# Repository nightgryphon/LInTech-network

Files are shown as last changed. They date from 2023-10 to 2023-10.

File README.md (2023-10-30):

# Сеть LInTech
Проект посвящен сбору информации, реконструкции и исследованию учебного сетевого комплекса LInTech для компьютерных классов СССР.

## История
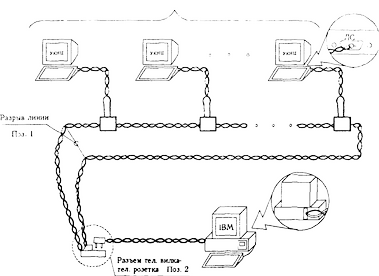
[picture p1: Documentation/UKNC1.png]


Комплекс был [разработан](https://dic.academic.ru/dic.nsf/ruwiki/46187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) в 1990-х гг. ООО «ЛИнТех» («Лаборатория информационных технологий») совместно с ООО «Алтер-Вест»
для модернизации существующих учебных классов на базе ПЭВМ Корвет, УКНЦ и БК0010 для изучения современного на тот момент ПО для IBM PC.

Обеспечивалась работа мест учеников в режимах локальной сети и в терминальном режиме.

Наиболее интересным и необычным для того времени является **терминальный режим**, в котором существующие места учеников становятся сетевыми терминалами для головной машины на базе IBM PC. 
Поддерживаются как режимы текстового терминала для изучения MS DOS, так и графического для изучения MS Windows 3.11. 

В режиме локальной сети ученикам предоставляется доступ к дискам головной машины, причем скорость работы заметно выше штатной учебной сети. 

Комплекс упоминается в [журналах](http://school136.perm.ru/sunduk/samos/info.htm) и документах 
министерства образования и был [рекомендован](http://web.archive.org/web/20070927175919/http://www.informika.ru/text/goscom/normdoc/d_96/PRIK~5/l155.html) к применению в школах.
Однако классы на базе ПЭВМ СССР на тот момент уже активно замещались западными PC, в том числе при активной поддержке западных производителей, 
в результате комплекс LInTech не успел получить широкого распространения и был практически утрачен.

В настоящее время ученические платы изредка встречаются в ПЭВМ, списаных из школ. Чаще всего это ПЭВМ Корвет, реже УКНЦ, также известно несколько экземпляров плат для БК. 
Долгое время не удавалось разыскать сетевую плату и ПО головной машины, без которых невозможна работа ни одной из этих сетей. 
На данный момент доподлинно известно о двух сохранившихся экземплярах головной платы и, возможно, еще одном.

Первый и пока единственный публично упомянутый запуск-реконструкция сети LInTech / NET-Rt11 осуществлены [Arseny](http://uknc.narod.ru/) для ПЭВМ УКНЦ (МС 0511). 
На его сайте представлены [качественные фото плат](http://uknc.narod.ru/Img/index.htm) и [комплект учительского ПО для УКНЦ](http://uknc.narod.ru/Net-RT11/index.htm).
Однако задача реконструкции комплекса на данном этапе была существенно затруднена отсутствием копии защищенной от чтения прошивки микроконтроллера головной платы.

Второй экземпляр головной платы и бумажную документацию удалось разыскать [Serebriakov](https://github.com/paulargent). 
Благодаря его усилиям были налажены контакты с разработчиками из ЛИнТех, получено оставшееся в архивах ПО и прошивки контроллера головной платы.
Это решило принципиальный вопрос с прошивками и сделало возможной дальнейшую реконструкцию системы. Также есть надежда, что со временем появится и электронная версия найденной документации.

Мне удалось разыскать и восстановить клиентские платы БК0010 и УКНЦ, найти около десятка контроллеров от платы головной машины (увы, без самих плат). 

Все это позволяет попробовать реконструировать и запустить сеть ЛИнТех.

## Реконструкция
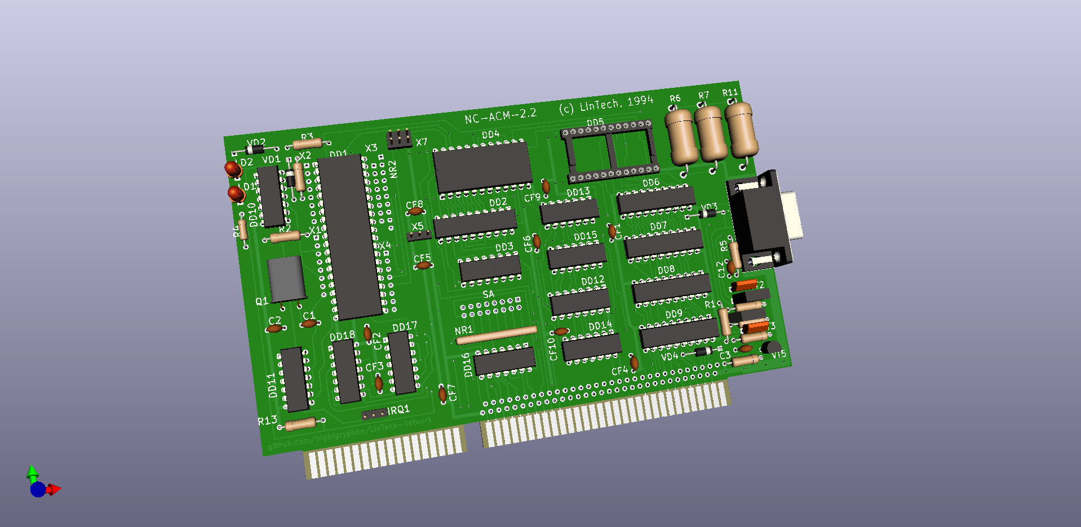
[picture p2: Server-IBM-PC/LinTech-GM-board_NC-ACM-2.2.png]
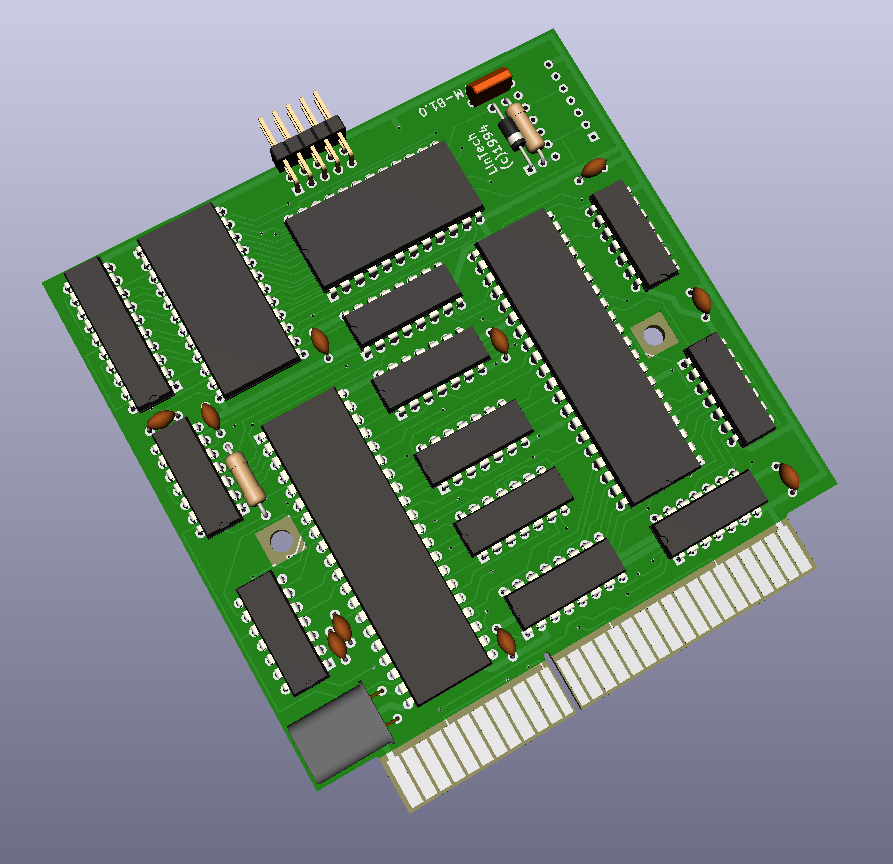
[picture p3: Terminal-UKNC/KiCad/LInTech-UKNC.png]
[](./Server-IBM-PC/)[](./Terminal-UKNC/)

Аппаратно комплекс реализован в виде клиентских плат, устанавливаемых в слоты расширения ПЭВМ учеников, и головной ISA платы для учительской IBM PC совместимой машины. 
Платы построены на основе микроконтроллеров Intel 8031 и 8051.

Связь в сети осуществляется по последовательной двухпроводной линии, что позволяет использовать существующую кабельную инфраструктуру компьютерных классов.

В качестве программного обеспечения были разработаны системы: 
- [NET-Rt11](https://www.emuverse.ru/wiki/%D0%A3%D0%9A%D0%9D%D0%A6_%D0%B6%D1%83%D1%80%D0%BD%D0%B0%D0%BB_1994-01_%D0%9B%D0%98%D0%BD%D0%A2%D0%B5%D1%85), 
- [DOS-Line](http://www.uw.ru/about/archive/dos-line/), 
- [NET-CP/M](https://oldkorvet.narod.ru/Utils.html)
- NET-БК0010

В данном проекте представлены:
- [Server-IBM-PC](./Server-IBM-PC/) - головная **[ учительская плата ISA для IBM PC ]** а так же **учительское ПО**
- [Terminal-UKNC](./Terminal-UKNC/) - клиентская плата УКНЦ
- [Terminal-BK0010](./Terminal-BK0010/) - клиентская плата БК 0010
- [Documentation](./Documentation/) - руководства

Дружественные проекты:
- [Терминал плата для ПЭВМ Корвет](https://github.com/lordamot/retro-lintech) была реконструирована коллегами NexusOfPenza и Lordamot

Платы в данном проекте не являются точной копией оригинала т.к. некоторые участки плат не видны под установлеными компонентами и невозможно сделать точную копию без разрушения оригинала. 
Реконструкция создана в KiCad с чистого листа имея оригинальную плату (или ее фото) в качестве образца. 
Не видимые элементы воссозданы путем отсмотра, прозвонки и изучения/воссоздания логики работы платы. 

Все данные публикуются с согласия представителя ЛИнТех.

## Ссылки
1. [academic.ru: Что такое УКНЦ? см раздел "Модернизация"](https://dic.academic.ru/dic.nsf/ruwiki/46187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)
2. [Каталог статей об УКНЦ (а также, о разработках фирмы ЛИнТех)](http://school136.perm.ru/sunduk/samos/info.htm)
3. [«NET-Rt11» — СЕТЕВАЯ СИСТЕМА ДЛЯ КУВТ «УКНЦ» С IBM-СОВМЕСТИМОЙ ГОЛОВНОЙ МАШИНОЙ](https://www.emuverse.ru/wiki/%D0%A3%D0%9A%D0%9D%D0%A6_%D0%B6%D1%83%D1%80%D0%BD%D0%B0%D0%BB_1994-01_%D0%9B%D0%98%D0%BD%D0%A2%D0%B5%D1%85)
4. [Приказ Мин Обр 'О модернизации отечественных КУВТ "Корвет" и УКНЦ' N 155/28 от 13.05.96г](http://web.archive.org/web/20070927175919/http://www.informika.ru/text/goscom/normdoc/d_96/PRIK~5/l155.html)
5. [Многозадачная, многопользовательская операционная система DOS-Line](http://www.uw.ru/about/archive/dos-line/)
6. [uknc.narod.ru: Фото от Arseny](http://uknc.narod.ru/Img/index.htm)
7. [uknc.narod.ru: оригиналы инструкции и ПО УКНЦ от Arseny](http://uknc.narod.ru/Net-RT11/index.htm)
8. [Старые фото и описание плат ЛИнТех от Serebriakov на форуме zx-pk.ru](https://zx-pk.ru/threads/2597?p=922488&viewfull=1#post922488)
9. [Образы дискет с установщиком ЛИнТех от Serebriakov на его старом сайте по Корвету oldkorvet.narod.ru)](https://oldkorvet.narod.ru/Utils.html)
10. [Дружественный проект по реконструкции платы для ПЭВМ Корвет от коллег NexusOfPenza и Lordamot](https://github.com/lordamot/retro-lintech)

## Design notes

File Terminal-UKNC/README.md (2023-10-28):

# LInTech - плата Терминальной Машины (ТМ) - клиента УКНЦ (Электроника МС 0511)
3D модель платы

Плата воссоздана [Night Gryphon](https://github.com/nightgryphon) по имеющемуся у него в наличии оригиналу платы.

Прошивка платы маркирована "КЛС-ТМ-BD1 П1 В1 Т03"

Содержание:
- KiCad - исходный проект реконструкции платы в формате KiCad
- Gerbers - GERBER файлы для изготовления реплики
- LinTech-UKNC-board-BOM.html - BOM, список компонентов
- LinTech-UKNC-board.pdf - реконструированая схема платы
- Firmware - микропрограмма контроллера Intel 8031
- Reference_Photo - фото платы

На данный момент реальные платы по данной реконструкции не изготавливались / не тестировались, в проекте возможны неточности.

## Техническое описание
**[WIP]**

Плата устанавливается в боковой разъем СА вместо штатной сетевой карты УКНЦ и подключается к сети обычным (существующим) кабелем через стандартную коммутационную коробку учебной сети УКНЦ.

Плата построена на базе микроконтроллера Intel 8031 (ДД1).
 
Программа контроллера размещена во внешнем ПЗУ (ДД6). ОЗУ контроллера расширено 573РУ10 (ДД5). 

Адресное пространство памяти данных контроллера разделено на 2 части:
- В младшей части расположено дополнительное ОЗУ
- В старшей - порты контроллера 580ВВ55А (ДД13)

Обмен с линией осуществляется по последовательному порту (RXD/TXD)

На порт Р1 выведены сигналы шины периферийного процессора УКНЦ:
0. SYNC
1. DIN 
2. DOUT
3. WTBT
4. RPLY
5. DMGO
6. DMR 
7. SACK

**[ToDo]**
Описание работы с МПИ/QBUS и прерываний

MCU Р3.5 - разрешение векторных прерываний
ДД12 - адрес векторного прерывания ( 0b 1110 0x00 ; x = ~ ВВ55-PC.7)

### Интерфейс УКНЦ
[ToDo]

## Описание микропрограммы
[Требуется помощь]

## Сетевой протокол
[Требуется помощь]

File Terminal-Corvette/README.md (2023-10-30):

# LInTech - плата Терминальной Машины (ТМ) - клиента ПК Корвет (ПК 8010/8020 «Корвет»)

Оригинальная плата версии 2.1 отсканирована и отрисована в формате DipTrace [в проекте](https://github.com/lordamot/retro-lintech) NexusOfPenza и Lordamot.

На основе данного проекта планируется воссоздать принципиальную схему и разводку платы в KiCad, подготовить файлы для производства реплики.

- В разделе Reference_Photo собраны фото и сканы различных вариантов данной платы и примеры ее установки от [Serebriakov](https://github.com/PaulArgent), [Lordamot](https://github.com/lordamot), [TomaTLAB](https://github.com/TomaTLAB).
- Firmware - микропрограммы (прошивки)

Отдельная благодарность Сергею Лемешеву aka [Lordamot](https://github.com/lordamot) и Антону Миронову aka [TomaTLAB](https://github.com/TomaTLAB) за повторное перечитывание прошивок своих плат и помощь Павлу Бардиловскому aka [Serebriakov](https://github.com/PaulArgent) с верификацией прошивок. Теперь все прошивки совпали как минимум в двух разных чипах в двух разных платах. Большинство же прошивок совпали в трех и более платах.

## Техническое описание
[WIP]

Плата построена на базе микроконтроллера серии Intel 8051 (Intel MCS-51). Обычно использовались:
- ATMEL AT89C51
- SIEMENS SAB8051A-P

Программа контроллера размещена во внешнем ПЗУ. Использовались EPROM 2716 (КС573РФ2, КС573РФ5) или EPROM 2732 в зависимости от наличия на заводе изготовителе.

## Интерфейс клиента ПК Корвет

## Описание микропрограммы

### Выбор номера Терминальной Машины

Каждая Терминальная Машина имеет свой номер в сети от 00 до 31. Максимальное количество машин в сети - 32, указано в описании прошивок серверных плат.

Номер терминала задается в прошивке EPROM 2716 - **П1** (чип слева на плате рядом с Intel 8051).

Так же номер указан на наклейках чипов ПЗУ либо микроконтроллера в формате: **Т00**, где  **00** - номер терминала. Например, **T07** для **7-ой** машины в сети.

Пример сравнения двух прошивок версии **B3** для **7-ой** машины в сети и **14-ой**. По смещению 0x53 виден байт, задающий номер терминала:

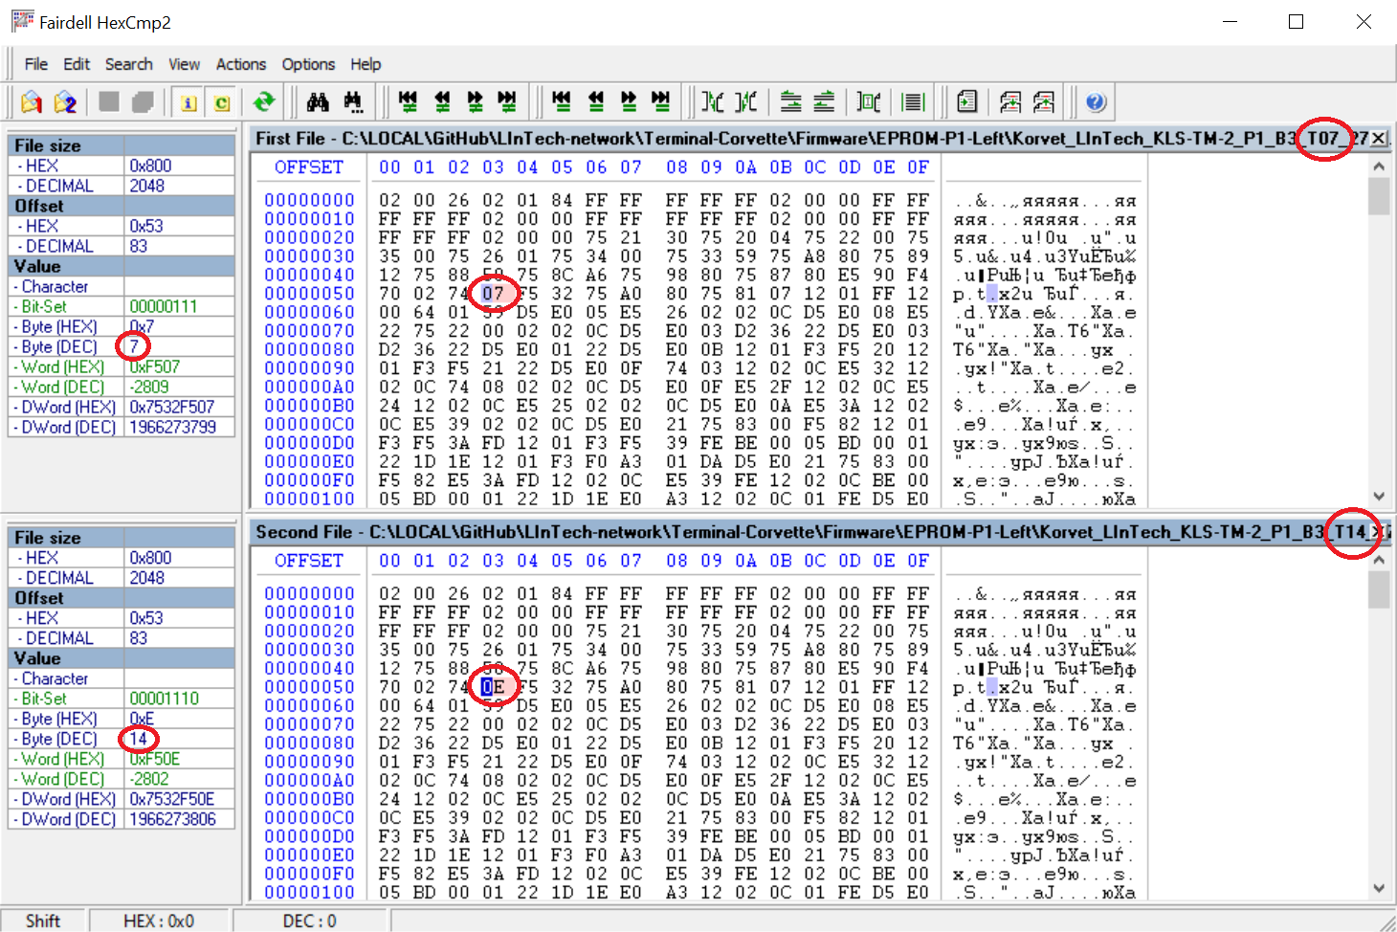
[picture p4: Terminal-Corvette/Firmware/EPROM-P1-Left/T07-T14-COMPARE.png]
[](Firmware/EPROM-P1-Left/T07-T14-COMPARE.png)

### Версии плат

Имеются две версии платы:
- c одним распаянным EPROM 2716:
  - **КЛС-ТМ-2 П0** - чип справа на плате
- c двумя распаянными EPROM 2716:
  - **КЛС-ТМ-2 П0** - чип справа на плате
  - **КЛС-ТМ-2 П1** - чип слева на плате рядом с Intel 8051

Все прошивки имеют размер 2кб (16кбит).

Прошивки в чипах П0 сопадают на платах с одним EPROM 2716 и двумя EPROM 2716.

На платах с EPROM 2732 4кб (32кбит), первые 2кб прошивки заполнены пустотой с кодом 0xFF (255), остальные 2кб - самой прошивкой, такой же как и в EPROM 2716 2кб (16кбит).

### Маркировка чипов

На платах обнаружились две версии прошивок: **B3** и **B3t**.

На версии платы с одним распаянным EPROM 2716, в отсутсвии второго чипа, вторая наклейка наклеяна на микроконтроллер Intel 8051 (серия Intel MCS-51):
- **КЛС - ТМ - 2 П1 B3t T00**

EPROM 2716 маркировались наклейками:
- **КЛС-ТМ-2 П0 B3** - чип справа на плате
- **КЛС-ТМ-2 П1 B3 T00** - чип слева на плате рядом с Intel 8051

или
- **КЛС-ТМ-2 П0 B3t** - чип справа на плате
- **КЛС-ТМ-2 П1 B3t T00** - чип слева на плате рядом с Intel 8051

в зависимости от версии прошивки внутри чипа.

Встречаются платы с перемешанными версиями прошивок на чипах, т.е. в **П0** зашита прошивка версии **B3**, а в **П1** прошивка версии **B3t** и наоборот: в **П0** - **B3t**, В **П1** - **B3**. Как это влияет на работу предстоит выяснить. Но в подавляющем большиснтве сохранившихся плат, прошивки обоих чипов EPROM все-таки имеюют одну и ту же версию прошивки - либо **B3**, либо **B3t**. 

# Сетевой протокол
[Требуется помощь]

# Ссылки
Дружественный проект по реконструкции платы для ПЭВМ Корвет от коллег NexusOfPenza и Lordamot
[https://github.com/lordamot/retro-lintech](https://github.com/lordamot/retro-lintech)

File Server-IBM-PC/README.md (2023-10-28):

# LInTech - плата Головной Машины (ГМ) - сервера IBM-PC
Реконструированая плата 2.2

Платы реконструированы [Night Gryphon](https://night-gryphon.ru/vcard) по фото/сканам оригиналов плат, имеющихся в наличии у [Arseny](https://uknc.narod.ru/) (NC-ACM-2.2-1994) и [Serebriakov](https://github.com/PaulArgent) (NC-ACM-2.3E-1996).

В данный момент заказываются тестовые образцы платы 2.3.

Отдельное спасибо:
- [Arseny](https://uknc.narod.ru/) за исходные и дополнительные фото оригинальной платы версии NC-ACM-2.2-1994, отсмотр/поиск/прозвонку непонятных мест
- [Serebriakov](https://github.com/PaulArgent) за качественные сканы и дополнительные фото оригинальной платы версии NC-ACM-2.3E-1996.
- [Maxiol](https://forum.maxiol.com/) за помощь в воссоздании/проверке аналоговой части схемы
- Станиславу Масловски за опознание маркировки компонентов

Содержание:
- KiCad - проект реконструкции плат в формате KiCad
- LinTech-GM-board_NC-ACM-\*.pdf - реконструированые **схемы** плат 2.2 и 2.3Е
- Gerbers - **GERBER** файлы и **BOM** (списки компонентов) 
- Firmware - микропрограмма контроллера Intel 8051. Варианты для разных КУВТ и с разными лицензиями, см. README файлы.
- Reference_Photo - исходные фото, по которым велась реконструкция
- Cable - фото и схема соединительного кабеля
- [Software](./Software/) - **ПО головной машины**

Библиотека прошивок микроконтроллера платы и учительское ПО любезно предоставлены Станиславом Кононовым из ЛИнТех при содействии [Serebriakov](https://github.com/PaulArgent).

### Плата версии 2.2 
реконструирована по фото и с непосредственной помощью [Arseny](http://uknc.narod.ru/). 
Реконструированая плата 2.2

### Плата версии 2.3Е
реконструирована по качественным сканам [Serebriakov](https://github.com/PaulArgent) и схеме платы 2.2. 
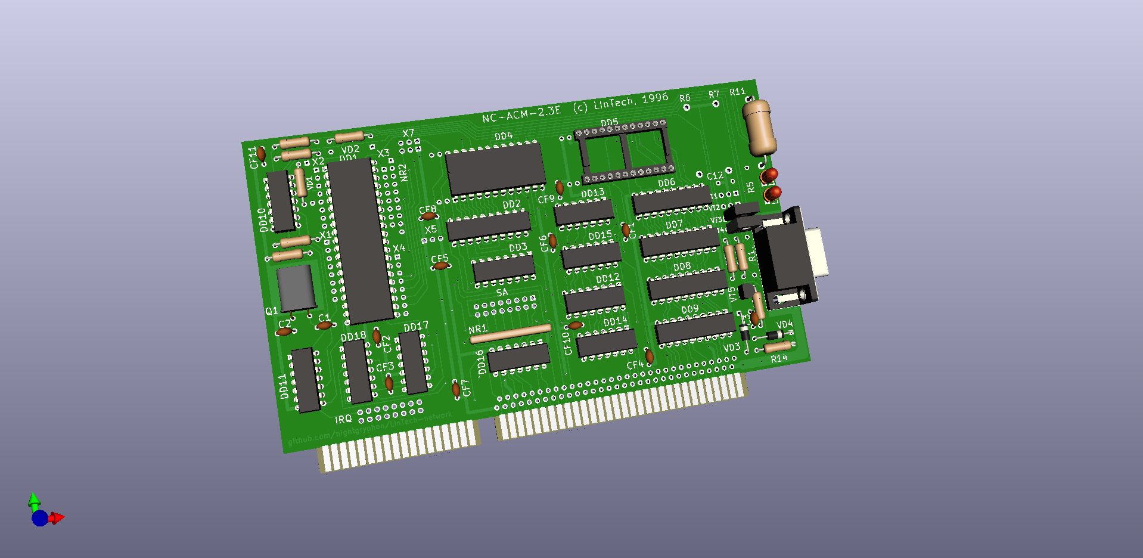
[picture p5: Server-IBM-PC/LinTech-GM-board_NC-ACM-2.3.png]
Реконструированая плата 2.3


**Плата 2.3 имеет следующие отличия:**
- расширен блок перемычек выбора прерывания. Теперь доступны прерывания 3, 4, 7, 10, 11 (по умолчанию), 12
- светодиоды перенесены рядом с планкой и теперь видны снаружи корпуса РС, светодиод LD2 на линии "Reset" заменен на зеленый.
- добавлена возможность не запаивать не использовать часть аналоговой схемы. Добавлен подтягивающий резистор R8.
- Транзистор VT3 заменен на КТ646Б, изменены номиналы некоторых резисторов/конденсаторов.
- линия запроса прерывания вынесена из под кварцевого резонатора и добавлен земляной полигон.
- блоки перемычек заменены печатными джамперами в положении по умолчанию

На момент публикации реальные платы по данной реконструкции не изготавливались / не тестировались в железе, в проекте возможны неточности.

Реконструированые платы не являются точной копией оригинала. Положение дорожек и их форма, положение компонентов незначительно отличаются от оригинала т.к. рисовались с нуля в своей сетке с учетом современных возможностей производства и т.д. 

## Техническое описание
**[WIP]**

Плата построена на базе микроконтроллера Intel 8051 (ДД1).
 
ОЗУ контроллера расширено 573РУ10 (ДД4). Возможно размещение в этом ОЗУ как данных так и исполнение кода.
Возможна работа с микропрограммой во внешнем ПЗУ (ДД5) (требует проверки) после установки джампера Х5 в положение 2-3.

Адресное пространство контроллера разбито на 4 части по старшим битам адреса 14 и 15, что реализуется дешифратором ДД3:
- В старшей части 0xFххх расположен порт данных обмена с РС построеный на 1533ИР22 (ДД6, ДД7). 
- В адресах 0х4ххх расположено дополнительное ОЗУ
- В адресах 0х0ххх (предположительно) может быть установлено ПЗУ с внешней микропрограммой (ДД5)

При получении данных от РС в порт данных - выдается прерывание Int0 (триггер ДД13-А). Младший бит адреса порта данных, в который производилась запись, может быть прочитан из порта Р3 бит 4.

При чтении РС из порта данных выдается прерывание Int1 (триггер ДД13-Б)

Для запроса прерывания на РС необходимо записать "1" в порт Р3 бит 5.

При перезагрузке РС по сигналу RESET на шине ISA микроконтроллер так же переводится в ресет до снятия бита ресета со стороны РС записью "0" в бит 7 порта управления.

Обмен с линией осуществляется через последовательный порт RXD/TXD.

### Интерфейс PC
Базовый адрес портов В/В выбирается перемычками SA.1-7 которые соответствуют битам 3-9 адреса порта.

По умолчанию:
0x0120, 0х0121 - порт данных (Port 67: ДД6, ДД7)
0x0122 - порт статуса и управления (Port 89: ДД8, ДД9)

Чтение:
	3 - "1" = поступили данные от контроллера
	4 - "1" = порт данных свободен, данные прочитаны контроллером
	5 - контроллер выход T1/Port3.5
	6 - "1" = разрешено прерывание
	7 - перемычка SA.8

Запись
	6 - "1" = разрешить прерывание
	7 - ресет контроллера. После перезагрузки PC контроллер находится в ресете и надо записать "0" в этот бит для старта платы.

Прерывание 11 (может быть изменено перемычками IRQ) - выход MCU Port3 bit 4, со стороны PC разрешается записью "1" в бит 6 регистра управления.

Известные проблемы платы:
- при использовании прерывания ISA у некоторых экземпляров платы происходили его ложные срабатывания/помехи вплоть до "завешивания" РС. 
Предположительно связано с разводкой линии прерывания на плате версии 2.2. В плате версии 2.3 это было изменено.

### Описание микропрограммы
[Требуется помощь]

## Сетевой протокол
[Требуется помощь]

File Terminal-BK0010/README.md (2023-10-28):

# LInTech - плата Терминальной Машины (ТМ) - клиента БК 0010

Плата в процессе воссоздания по имеющемуся у [Night Gryphon](https://github.com/nightgryphon) в наличии оригиналу.

Прошивка платы маркирована "КЛС-ТМ-N1 П0 В1 Т09"

- Reference_Photo - фото платы
- Firmware - микропрограмма контроллера Intel 8031

## Техническое описание
[WIP]
Плата построена на базе микроконтроллера Intel 8031 - DD1.
 
Программа контроллера размещена во внешнем ПЗУ. ОЗУ контроллера расширено 573РУ10. 
Помимо памяти контроллера плата содержит дополнительное ОЗУ для БК.

## Интерфейс БК МПИ

## Описание микропрограммы
[Требуется помощь]

## Сетевой протокол
[Требуется помощь]

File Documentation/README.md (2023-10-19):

## Документация

- Net-RT11_User_Manual.doc - NET-Rt11 & DOS-Line V2.0, Руководство пользователя(~0.9Mb) [UKNC.narod.ru](http://uknc.narod.ru/Net-RT11/index.htm)

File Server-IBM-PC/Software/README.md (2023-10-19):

## ПО ЛИнТех

### [UKNC.narod.ru](http://uknc.narod.ru/Net-RT11/index.htm)
ПО из комплекта с сайта UKNC.narod.ru
- Net-RT11.rar - Инсталляция Net-RT11 (серверная часть для IBM PC) (~0.7Mb)
- dosline_disk1.rar - Инсталляция Net-RT11 V2.0 (диск 1) (~1.0Mb)
- dosline_disk2.rar - Инсталляция Net-RT11 V2.0 (диск 2) (~1.1Mb)

### LInTech
ПО, предоставленное ЛИнТех (Станислав Кононов):
- NET-BK10
- NET-CPM
- NET-DEMO
- NET-RT11
- Triton-2
- Приложения

Обращайте внимание на файлы README внутри архивов.

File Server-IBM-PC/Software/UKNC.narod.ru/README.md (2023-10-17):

ПО из комплекта с сайта [UKNC.narod.ru](http://uknc.narod.ru/Net-RT11/index.htm)

- Net-RT11.rar - Инсталляция Net-RT11 (серверная часть для IBM PC) (~0.7Mb)

Работает в DOS (в Windows не попробовал). Расчитана на машины 386 и выше. Связь в сетью УКНЦ через спец. плату (ISA формата). Загрузка на УКНЦ учеников - обычная, из сети.
Насколько я помню, позволяет "запускать" на УКНЦ DOS и Windows 3.1 ;-)

- dosline_disk1.rar - Инсталляция Net-RT11 V2.0 (диск 1) (~1.0Mb)
- dosline_disk2.rar - Инсталляция Net-RT11 V2.0 (диск 2) (~1.1Mb)

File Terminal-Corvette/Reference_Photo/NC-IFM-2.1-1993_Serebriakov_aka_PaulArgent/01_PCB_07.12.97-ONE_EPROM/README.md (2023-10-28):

# Референс платы для Корвета 01

В данной плате отсутсвует второй чип EPROM 2716 - на других платах впаян слева на плате рядом с MCU Intel 8051.

Наклейки на чипах:
- КЛС - ТМ - 2 П1 **B3t** T00 - наклейка на MCU Intel 8051
- КЛС-ТМ-2 П0 **B3t** - наклейка на EPROM 2716 справа на плате

Возможно вторая прошивка зашита в MCU Intel 8051 (проверить нельзя, т.к. чип залочен).

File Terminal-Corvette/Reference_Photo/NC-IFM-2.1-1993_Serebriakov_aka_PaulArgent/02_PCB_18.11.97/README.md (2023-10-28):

# Референс платы для Корвета 02

По какой-то неизвестной причине в данной плате стоят чипы с разными версиями прошивок (наоборот относительно платы 04):
- КЛС-ТМ-2 П1 **B3** T14 - чип слева на плате рядом с Intel 8051 - наклейка была содрана, выяснил по содержимому чипа
- КЛС-ТМ-2 П0 **B3t** - чип справа на плате

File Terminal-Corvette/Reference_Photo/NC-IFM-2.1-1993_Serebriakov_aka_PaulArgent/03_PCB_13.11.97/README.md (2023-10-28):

# Референс платы для Корвета 03

В данной плате стоят чипы с одинаковыми версиями прошивок (и по наклейкам и по содержимому):
- КЛС-ТМ-2 П1 **B3t** T00 - чип слева на плате рядом с Intel 8051
- КЛС-ТМ-2 П0 **B3t** - чип справа на плате

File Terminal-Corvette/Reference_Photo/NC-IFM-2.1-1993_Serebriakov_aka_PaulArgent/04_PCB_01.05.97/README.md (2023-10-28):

# Референс платы для Корвета 04

По какой-то неизвестной причине в данной плате стоят чипы с разными версиями прошивок (наоборот относительно платы 02):
- КЛС-ТМ-2 П1 **B3t** T14 - чип слева на плате рядом с Intel 8051 - наклейка была содрана, выяснил по содержимому чипа
- КЛС-ТМ-2 П0 **B3** - чип справа на плате

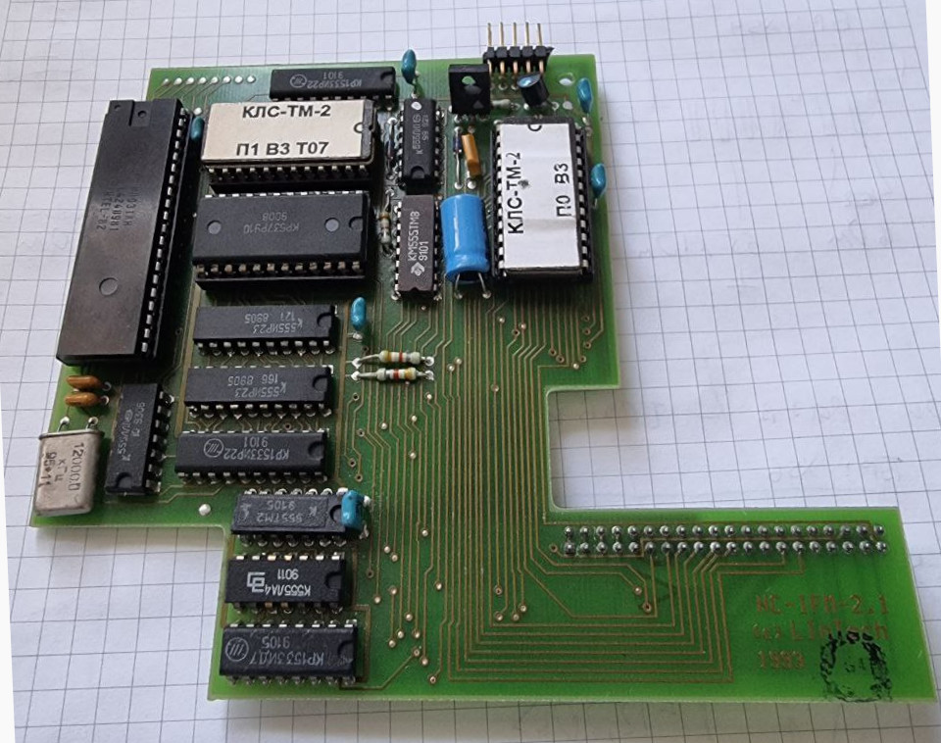
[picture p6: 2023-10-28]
Terminal-Corvette/Reference_Photo/NC-IFM-2.1-1993_lordamot_aka_Sergey_Lemeshev/03_NC-IFM-2.1-1993_Front_Photo_MCU.jpg

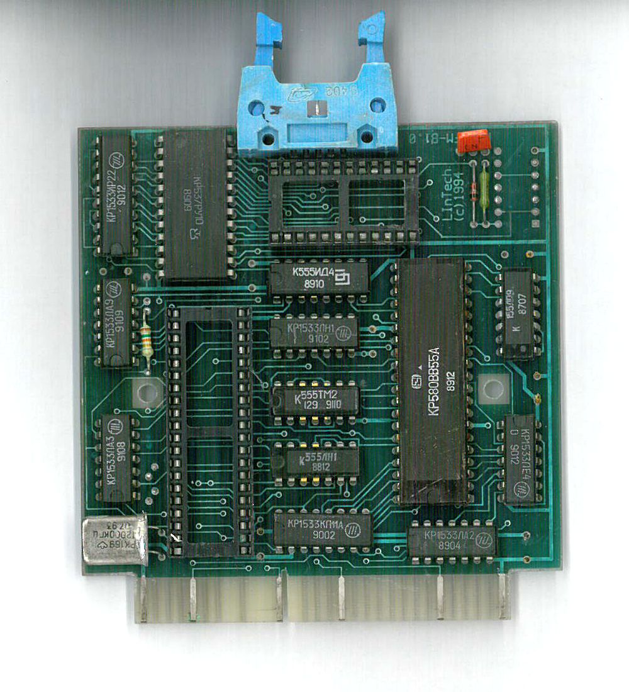
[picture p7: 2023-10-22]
Terminal-UKNC/Reference_Photo/NC-IFM-B1.0-1994_Night_Gryphon/01_NC-IFM-B1.0-1994_Front_Scan.jpg

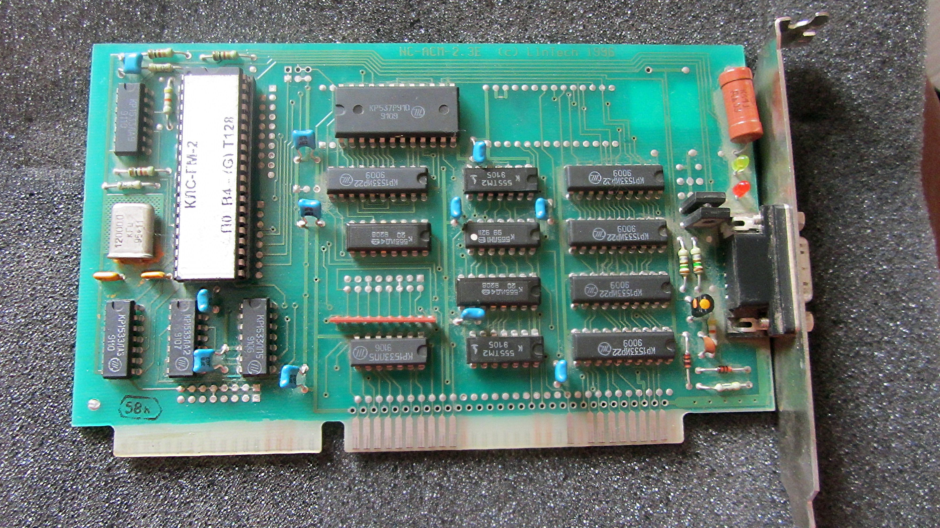
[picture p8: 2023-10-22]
Server-IBM-PC/Reference_Photo/NC-ACM-2.3E-1996_Serebriakov_aka_PaulArgent/04_NC-ACM-2.3E-1996_Front_Photo.jpg

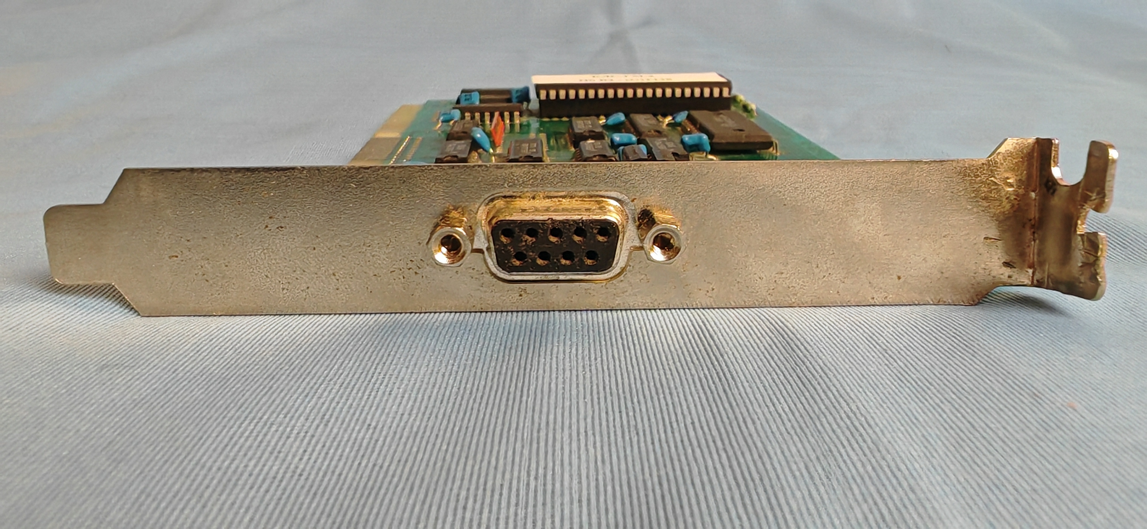
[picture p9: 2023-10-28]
Server-IBM-PC/Reference_Photo/NC-ACM-2.3E-1996_Serebriakov_aka_PaulArgent/08_NC-ACM-2.3E-1996_Shield_Back_Plate_Bracket_Photo.jpg

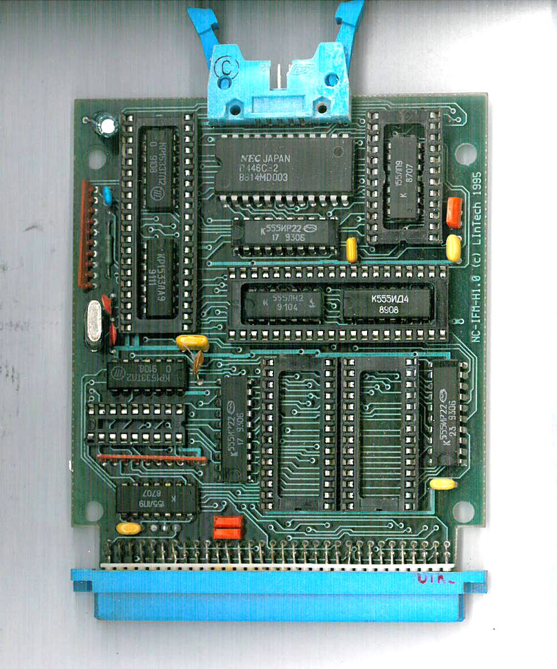
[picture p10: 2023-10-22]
Terminal-BK0010/Reference_Photo/NC-IFM-H1.0-1995_Night_Gryphon/01_NC-IFM-H1.0-1995-Front-Scan.jpg

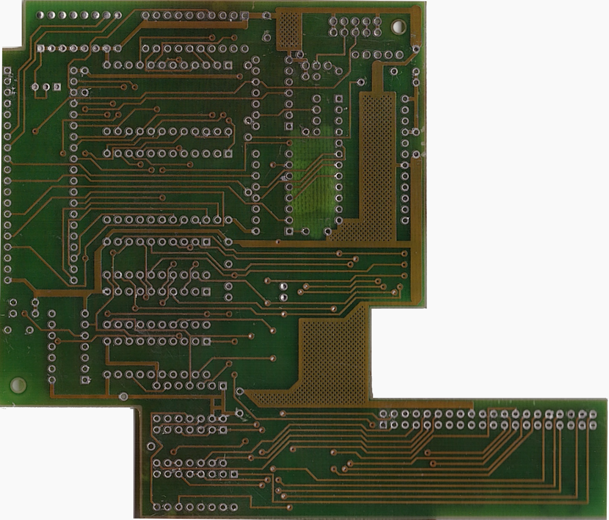
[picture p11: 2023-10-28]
Terminal-Corvette/Reference_Photo/NC-IFM-2.1-1993_lordamot_aka_Sergey_Lemeshev/02_NC-IFM-2.1-1993_Back_Scan.png

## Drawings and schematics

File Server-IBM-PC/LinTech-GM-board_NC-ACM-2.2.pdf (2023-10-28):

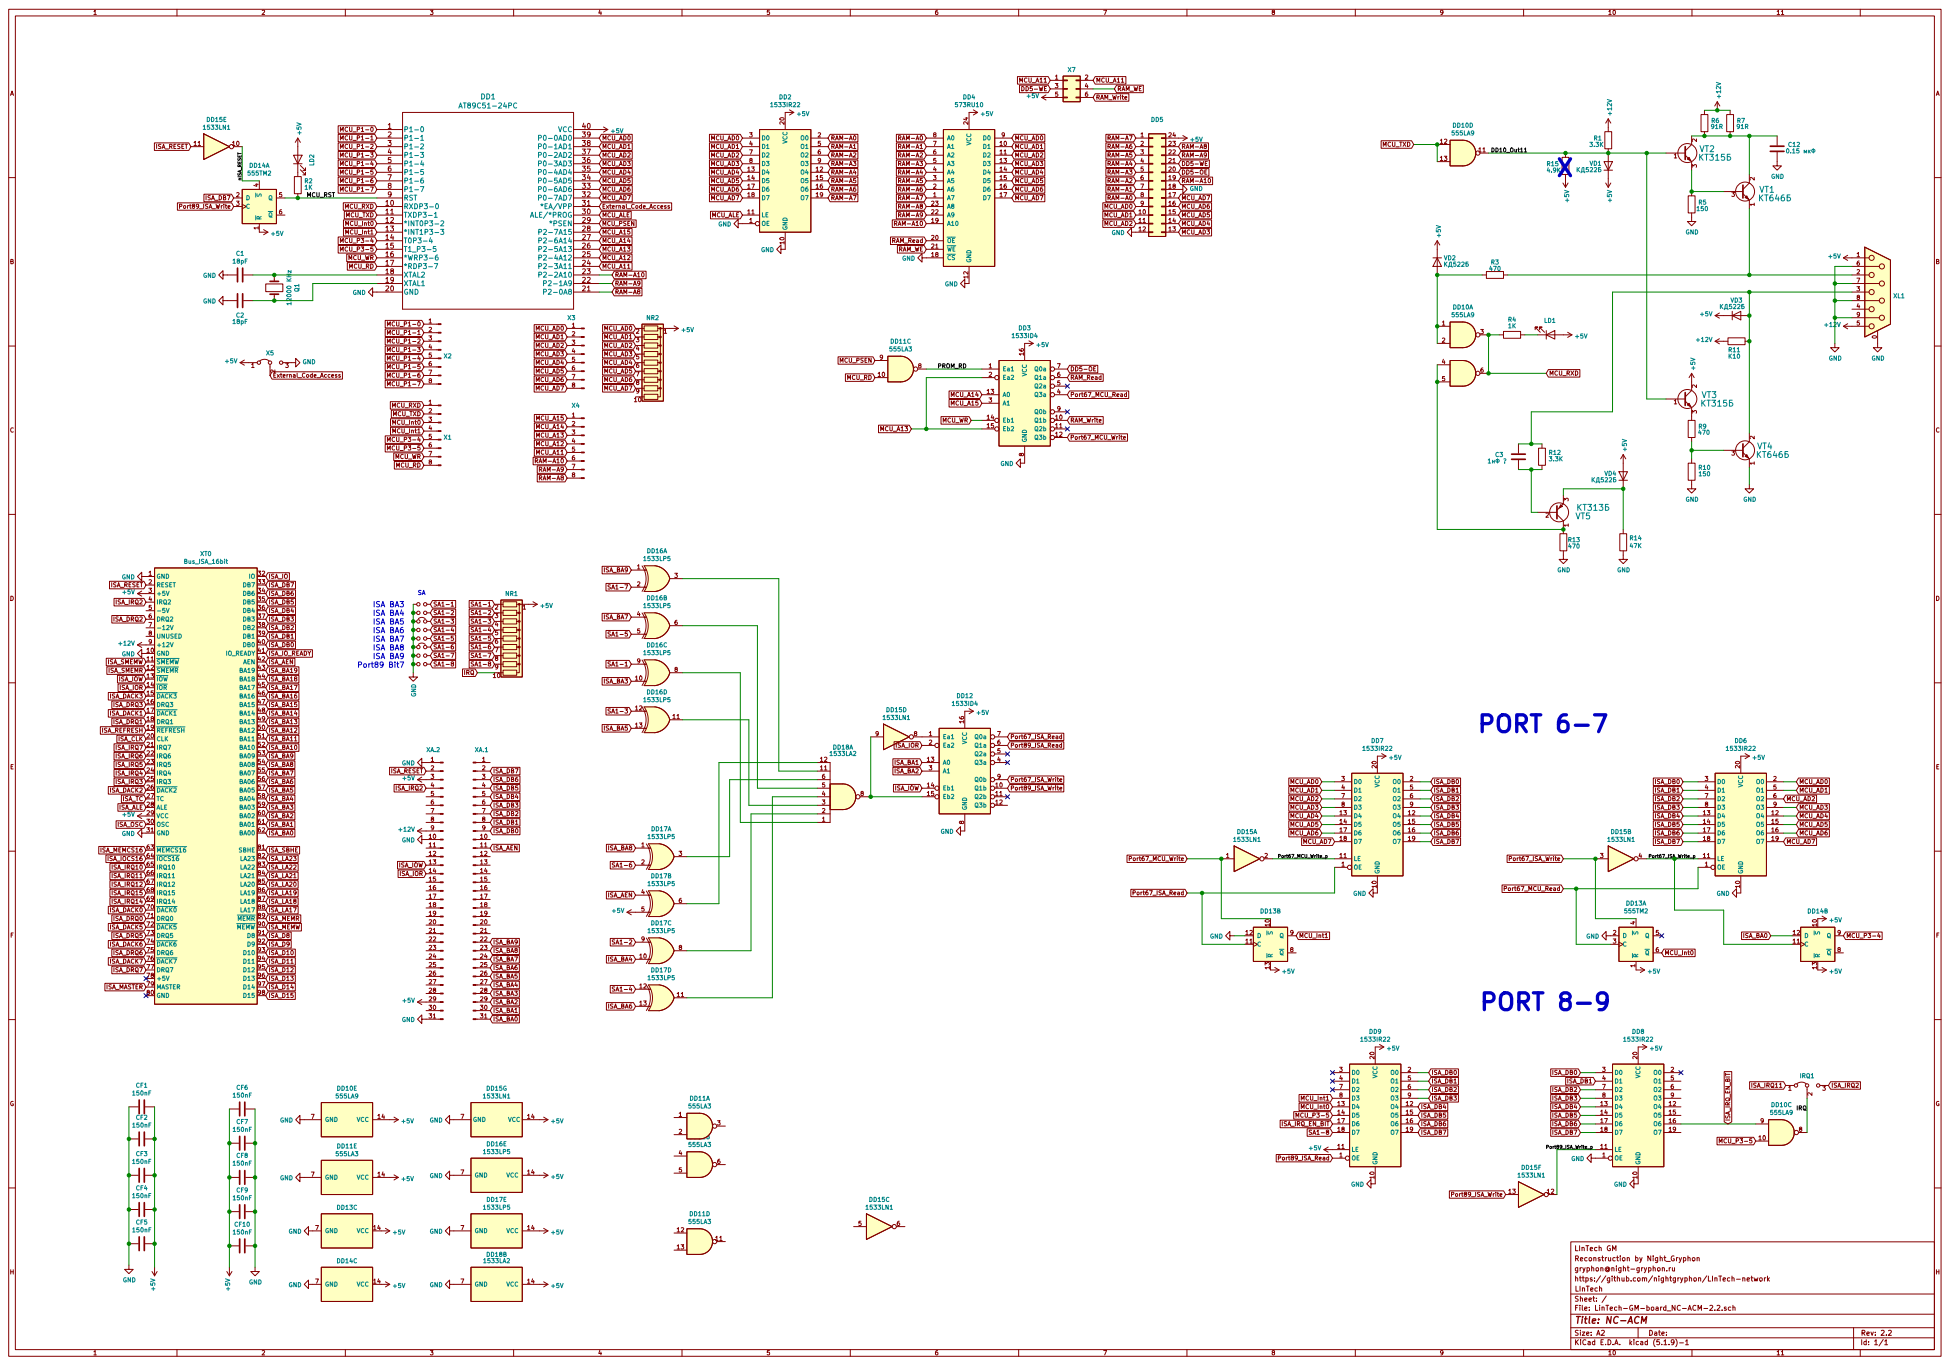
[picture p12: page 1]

LInTech GM
Reconstruction by Night_Gryphon
gryphon@night-gryphon.ru
https://github.com/nightgryphon/LInTech-network
File: LinTech-GM-board_NC-ACM-2.2.sch Sheet: / LInTech

Id: 1/1 Title: NC-ACM

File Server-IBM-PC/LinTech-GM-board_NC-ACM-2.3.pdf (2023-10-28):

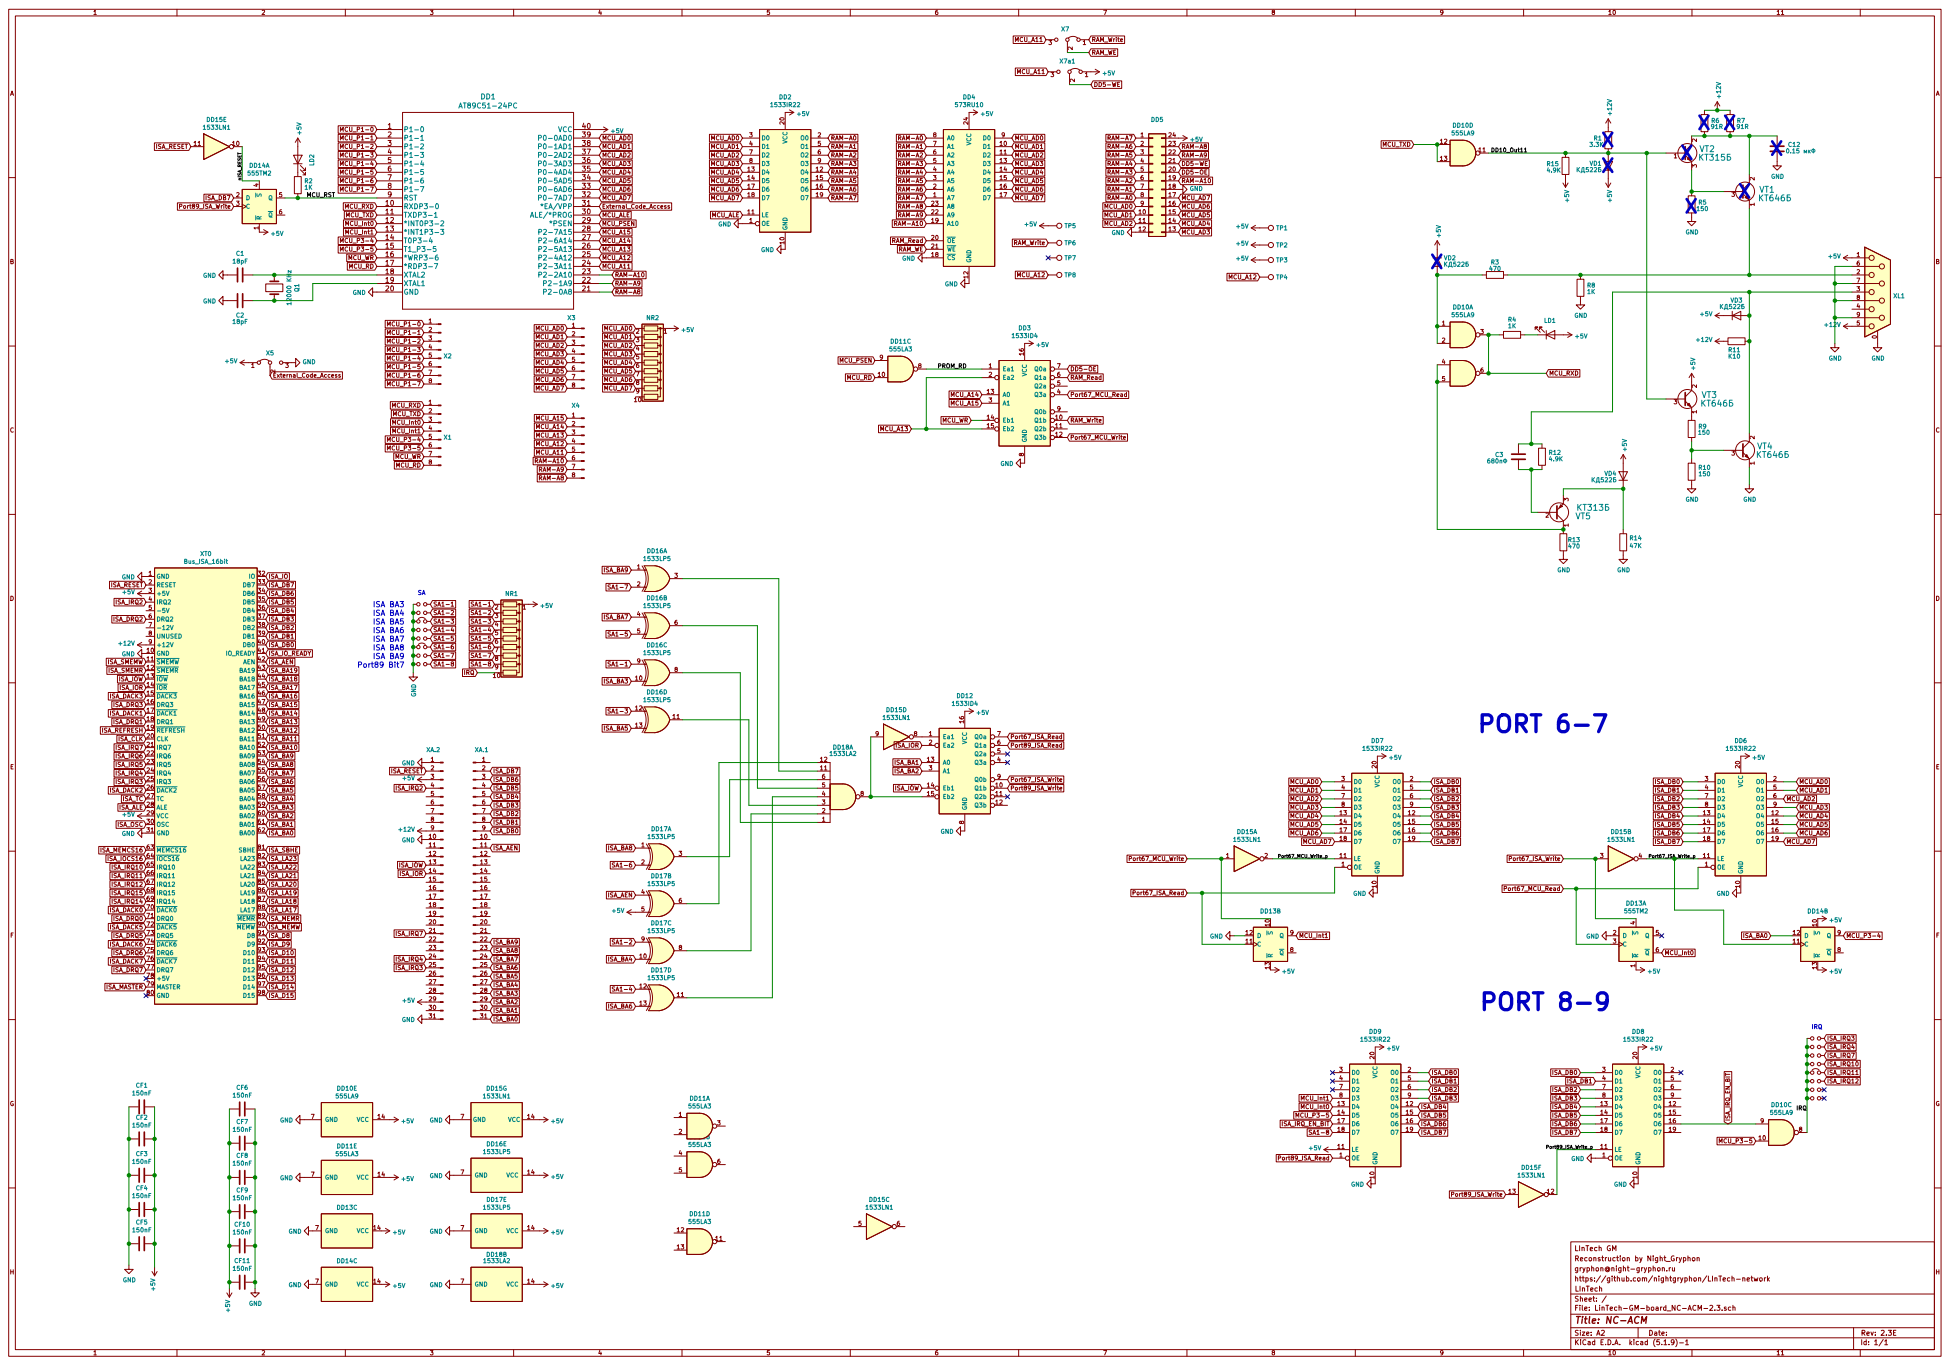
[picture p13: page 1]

GND GND

LInTech GM
Reconstruction by Night_Gryphon
gryphon@night-gryphon.ru
https://github.com/nightgryphon/LInTech-network
File: LinTech-GM-board_NC-ACM-2.3.sch Sheet: / LInTech

Id: 1/1 Title: NC-ACM

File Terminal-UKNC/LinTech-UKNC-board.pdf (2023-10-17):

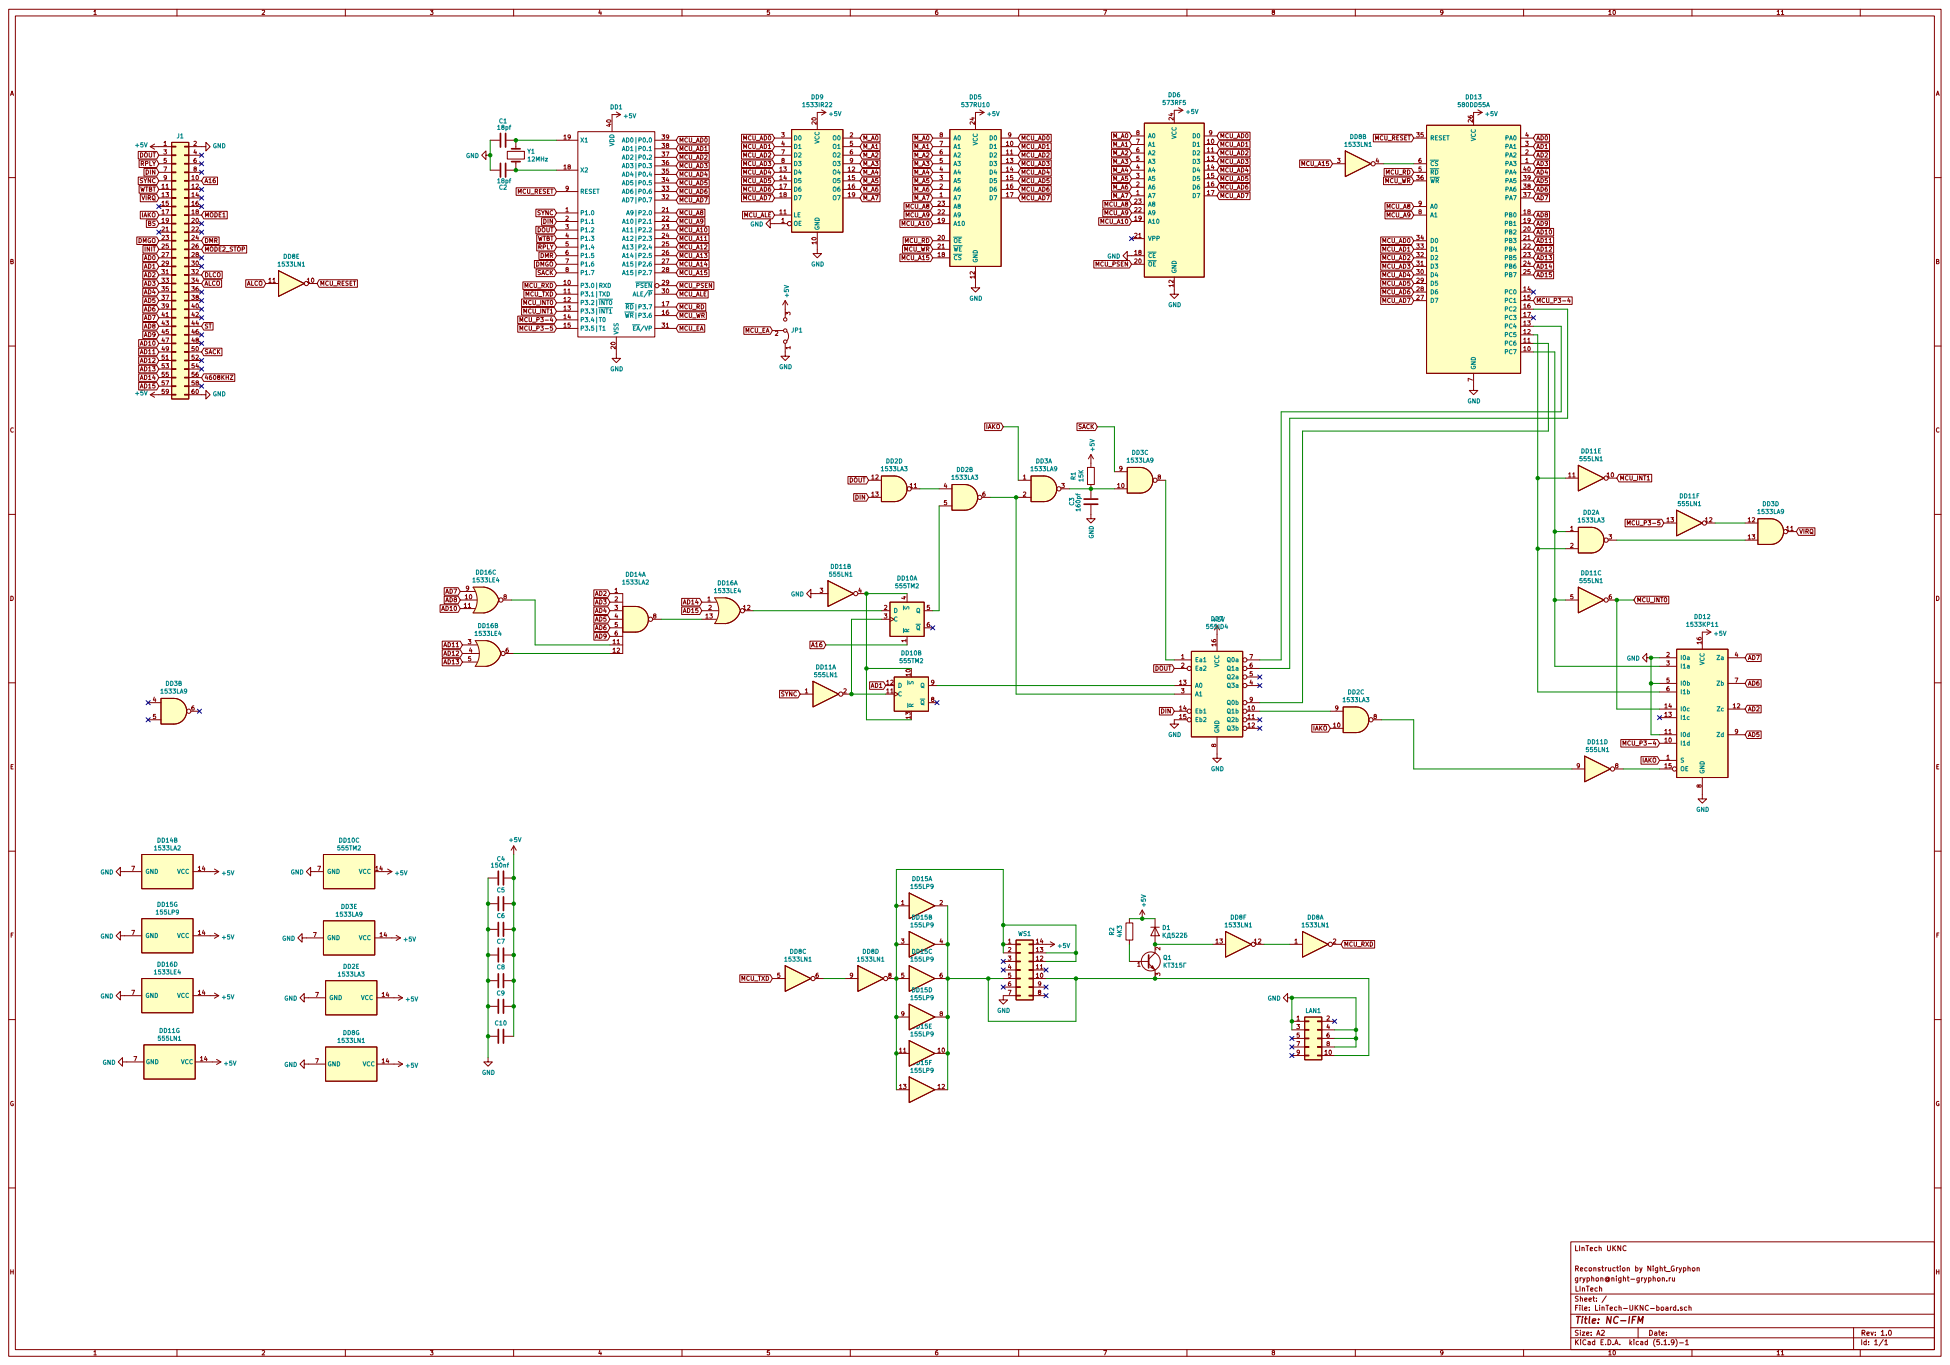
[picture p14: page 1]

Reconstruction by Night_Gryphon
gryphon@night-gryphon.ru
File: LinTech-UKNC-board.sch Sheet: / LInTech

Id: 1/1 Title: NC-IFM

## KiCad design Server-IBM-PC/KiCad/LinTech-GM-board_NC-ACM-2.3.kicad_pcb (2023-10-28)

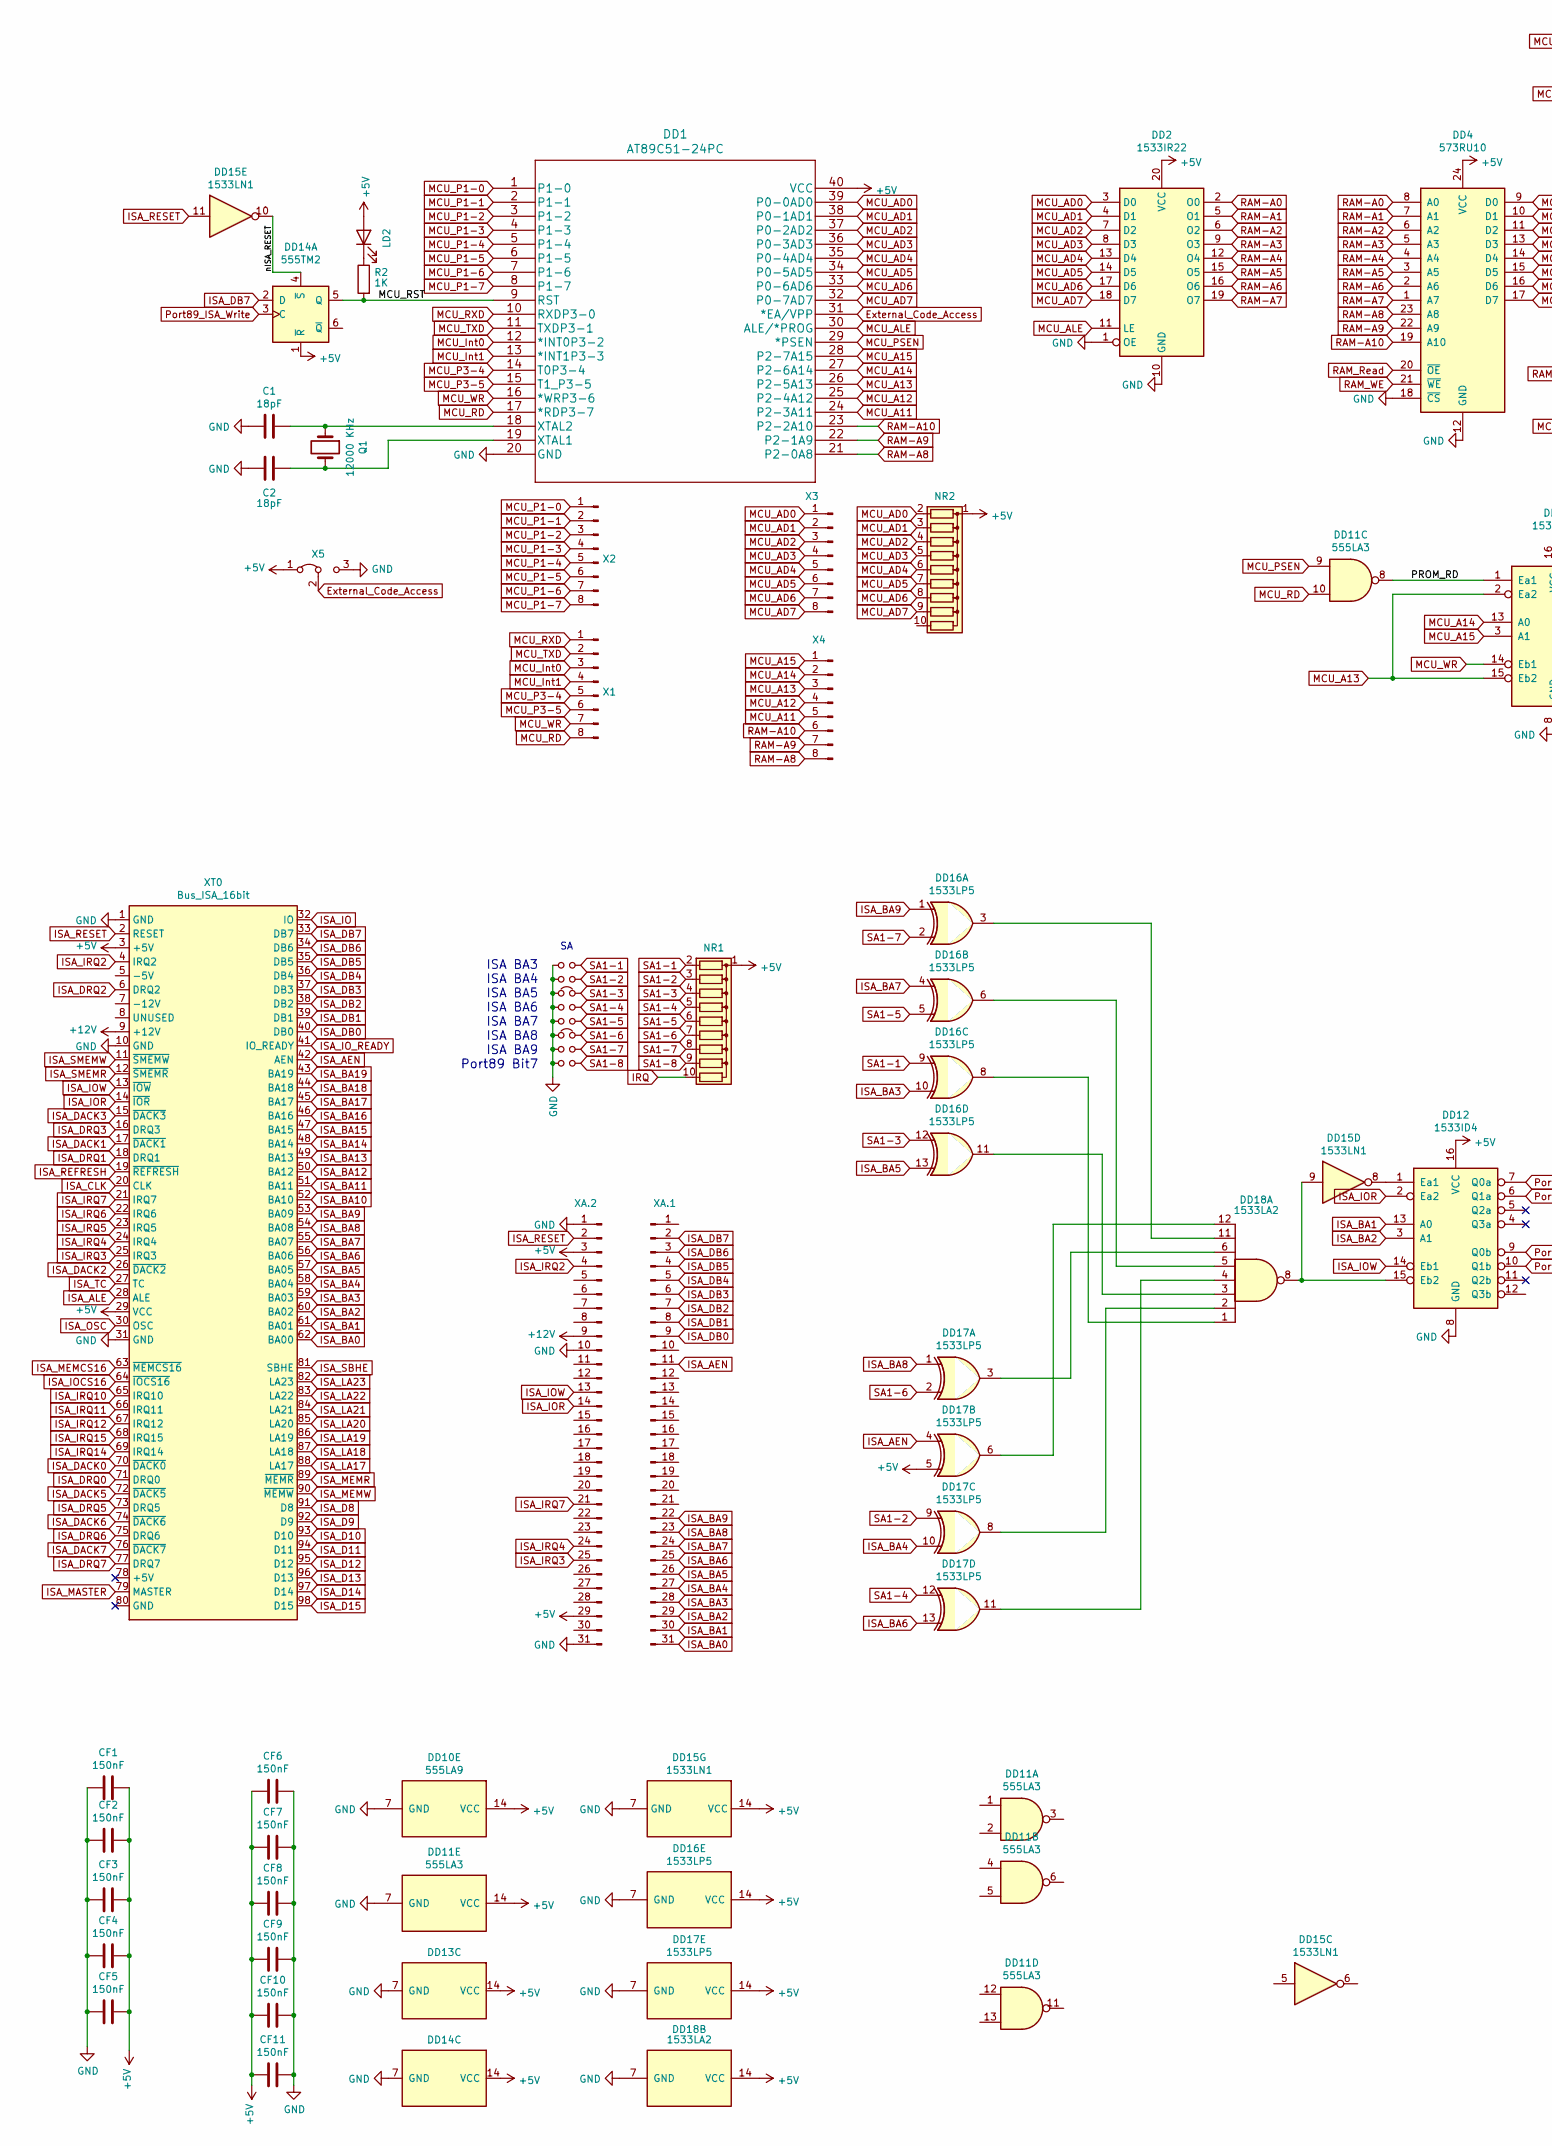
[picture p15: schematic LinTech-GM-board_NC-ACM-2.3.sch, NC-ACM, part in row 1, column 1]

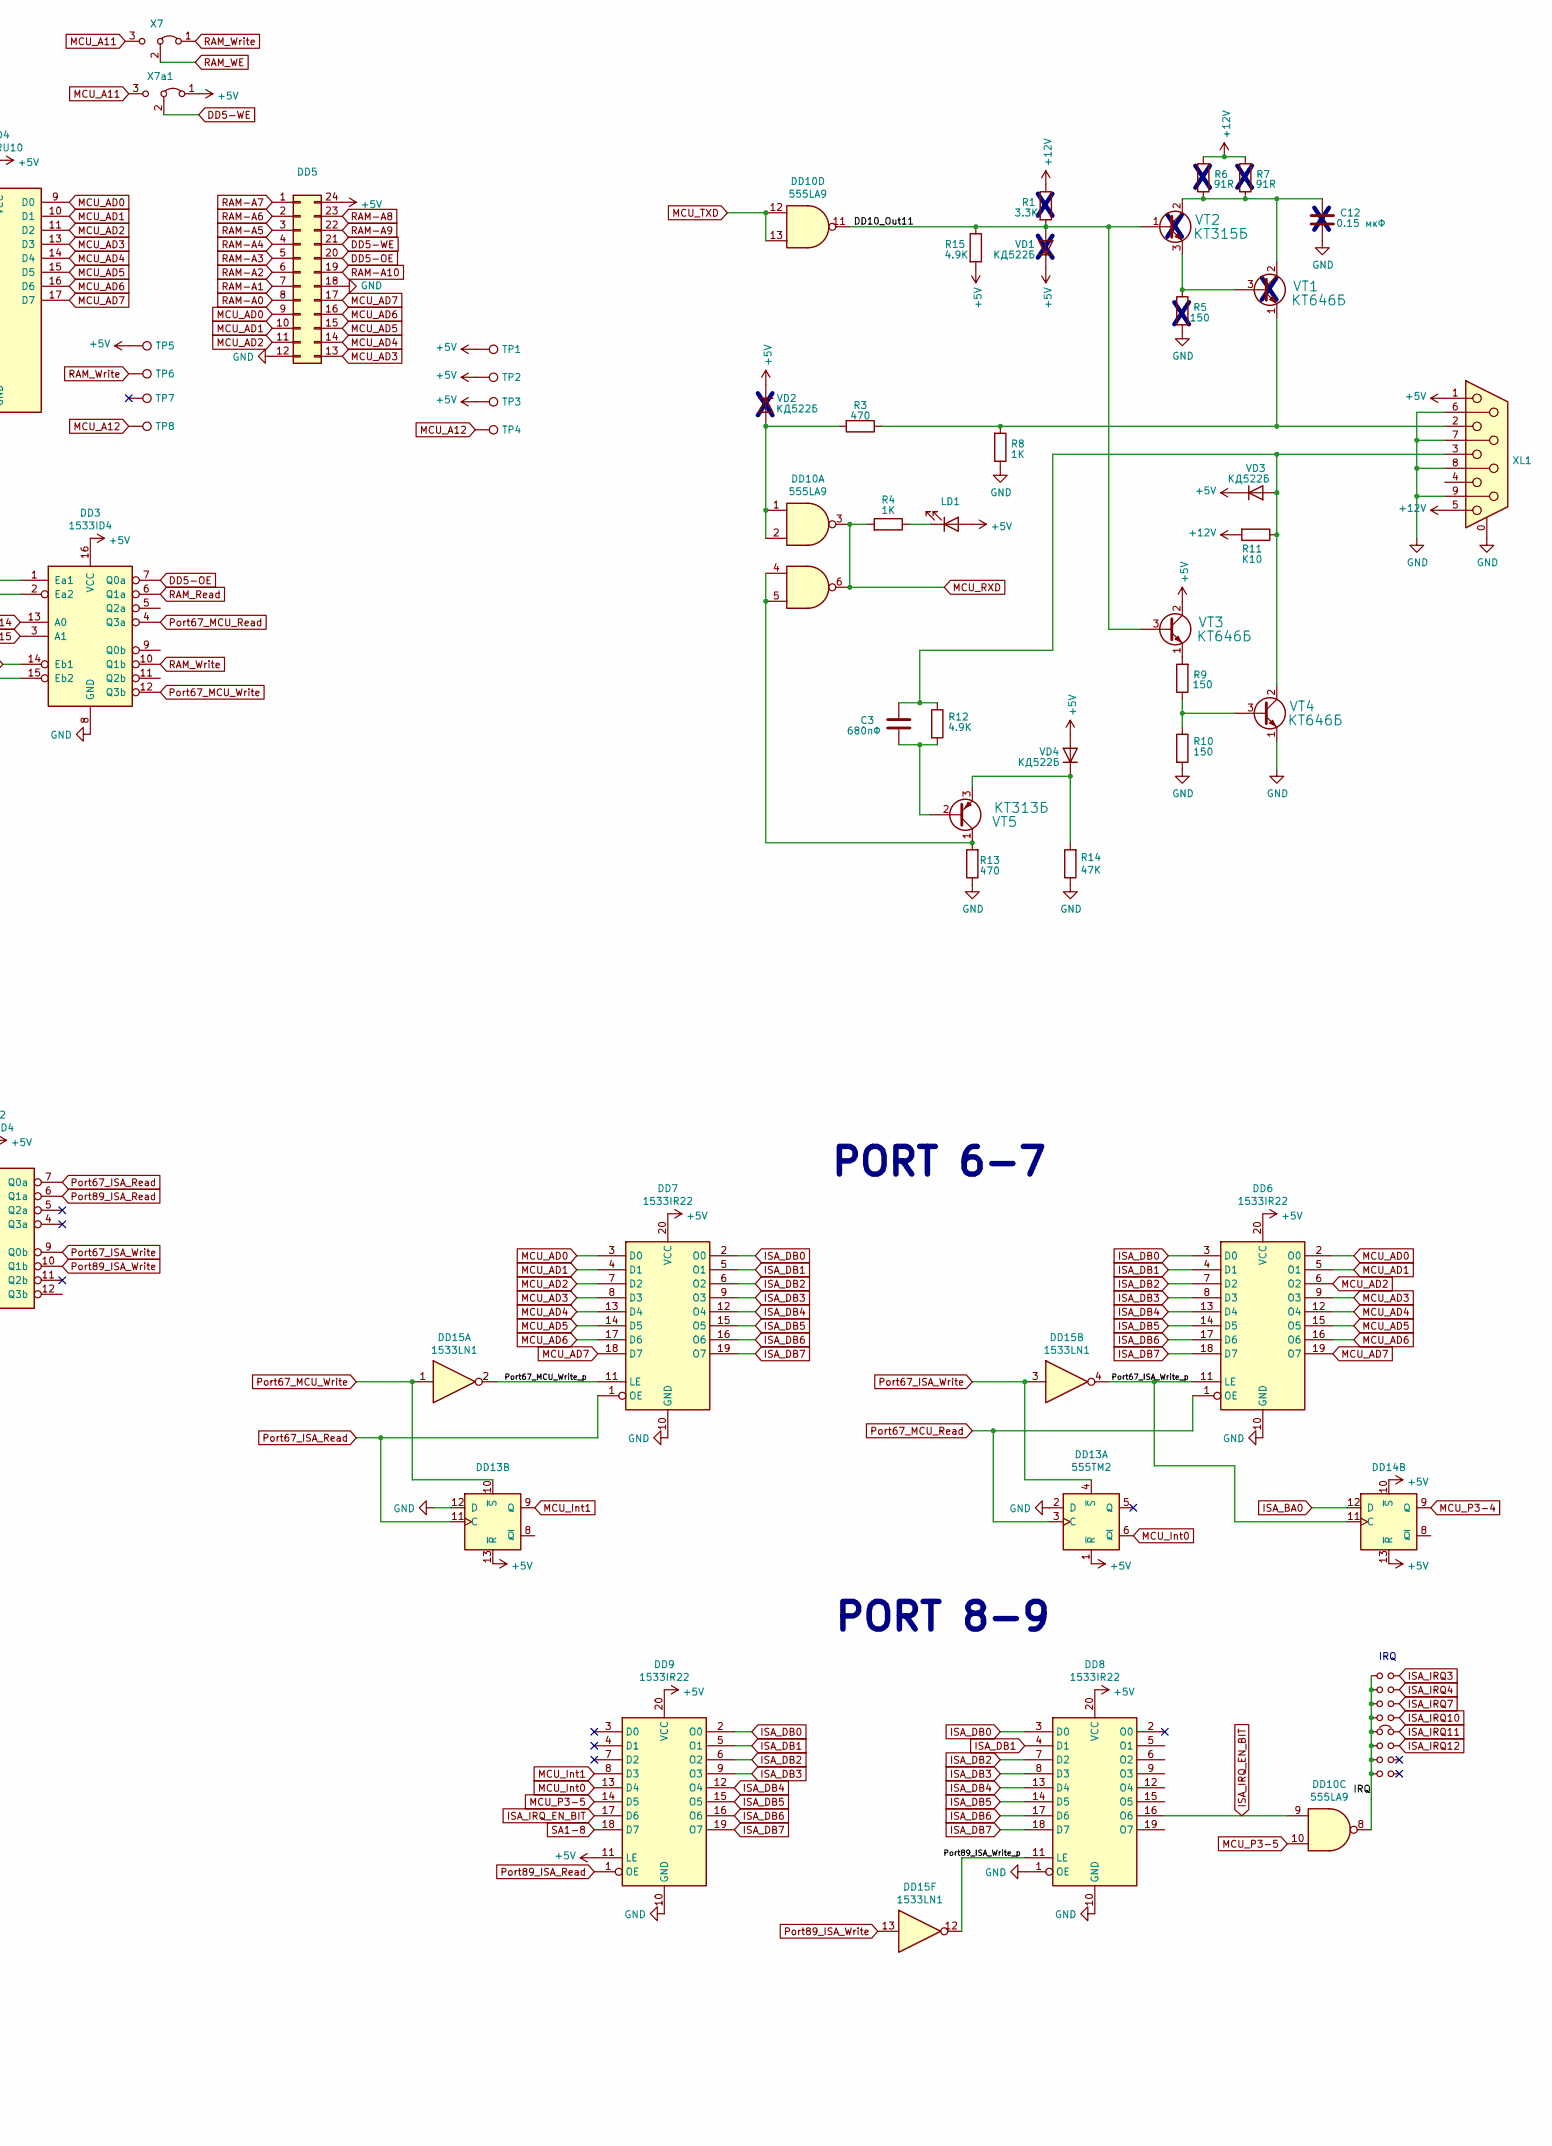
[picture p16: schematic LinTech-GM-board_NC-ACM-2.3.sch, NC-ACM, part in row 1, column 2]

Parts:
C1, C2: 18pF; C_Disc_D5.0mm_W2.5mm_P5.00mm
C3: 680пФ; C_Disc_D5.0mm_W2.5mm_P5.00mm
C12: 0.15 мкФ; C_Disc_D5.0mm_W2.5mm_P5.00mm
CF1, CF2, CF3, CF4, CF5, CF6, CF7, CF8, CF9, CF10, CF11: 150nF; C_Disc_D5.0mm_W2.5mm_P5.00mm
DD1: AT89C51-24PC; DIP-40_W15.24mm
DD2, DD6, DD7, DD8, DD9: 1533IR22; DIP-20_W7.62mm
DD3, DD12: 1533ID4; DIP-16_W7.62mm
DD4: 573RU10; DIP-24_W15.24mm
DD5: Socket DIP24; DIP-24_W15.24mm_Socket
DD10: 555LA9; DIP-14_W7.62mm
DD11: 555LA3; DIP-14_W7.62mm
DD13, DD14: 555TM2; DIP-14_W7.62mm
DD15: 1533LN1; DIP-14_W7.62mm
DD16, DD17: 1533LP5; DIP-14_W7.62mm
DD18: 1533LA2; DIP-14_W7.62mm
LD1: LED Red 4mm; LED_D4.0mm
LD2: LED Green 4mm; LED_D4.0mm
NR1: 3.3K ?; R_Array_SIP10
NR2: R_Array_SIP10
Q1: 12000 KHz; Crystal_HC18-U_Horizontal
R1: 3.3K; R_Axial_DIN0309_L9.0mm_D3.2mm_P12.70mm_Horizontal
R2, R4, R8: 1K; R_Axial_DIN0309_L9.0mm_D3.2mm_P12.70mm_Horizontal
R3, R13: 470; R_Axial_DIN0309_L9.0mm_D3.2mm_P12.70mm_Horizontal
R5, R9, R10: 150; R_Axial_DIN0309_L9.0mm_D3.2mm_P12.70mm_Horizontal
R6, R7: 91R; R_Axial_DIN0918_L18.0mm_D9.0mm_P22.86mm_Horizontal
R11: K10; R_Axial_DIN0918_L18.0mm_D9.0mm_P22.86mm_Horizontal
R12, R15: 4.9K; R_Axial_DIN0309_L9.0mm_D3.2mm_P12.70mm_Horizontal
R14: 47K; R_Axial_DIN0309_L9.0mm_D3.2mm_P12.70mm_Horizontal
SAjp1, SAjp2, SAjp4, SAjp5, SAjp7, SAjp8, SAjp9, SAjp10, SAjp11, SAjp12, SAjp14, SAjp15, SAjp16: Jumper_P2.54mm_Open
SAjp3, SAjp6, SAjp13: Jumper_P2.54mm_Close
TP1, TP2, TP3, TP4, TP5, TP6, TP7, TP8: TestPoint; TestPad
VD1, VD2, VD3, VD4: КД522Б; D_A-405_P12.70mm_Horizontal
VT1, VT3, VT4: КТ646Б; TO-126-3_Vertical
VT2: КТ315Б; TO-92S_Wide
VT5: КТ313Б; TO-92
X1, X2, X3, X4: PinHeader_1x08_P2.54mm_Vertical
X5: PinHeader_1x03_P2.54mm_Vertical
X7, X7a1: Conn_02x03_Counter_Clockwise; Jumper3_12closed_P2.54mm
XA.1, XA.2: PinHeader_1x31_P2.54mm_Vertical
XL1: DB9_Female; DSUB-9_Female_Horizontal_P2.77x2.84mm_EdgePinOffset7.70mm_H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
XT0: Bus_ISA_16bit; BUS_AT

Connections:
+5V: CF1.2, CF2.1, CF3.2, CF4.2, CF5.1, CF6.2, CF7.2, CF8.1, CF9.2, CF10.2, CF11.2, DD1.40 (VCC), DD2.20 (VCC), DD3.16 (VCC), DD4.24 (VCC), DD5.24, DD6.20 (VCC), DD7.20 (VCC), DD8.20 (VCC), DD9.11 (LE), DD9.20 (VCC), DD10.14 (VCC), DD11.14 (VCC), DD12.16 (VCC), DD13.1 (~R), DD13.13 (~R), DD13.14 (VCC), DD14.1 (~R), DD14.10 (~S), DD14.13 (~R), DD14.14 (VCC), DD15.14 (VCC), DD16.14 (VCC), DD17.5, DD17.14 (VCC), DD18.14 (VCC), LD1.2 (A), LD2.2 (A), NR1.1 (common), NR2.1 (common), R15.2, TP1.1, TP2.1, TP3.1, TP5.1, VD1.1 (K), VD2.1 (K), VD3.1 (K), VD4.2 (A), VT3.2 (C), X5.1 (A), X7a1.1 (A), XA.2.3, XA.2.29, XL1.1, XT0.3 (+5V), XT0.29 (VCC)
+12V: R1.1, R6.2, R7.2, R11.2, XA.2.9, XL1.5, XT0.9 (+12V)
/DD10_Out11: DD10.11, R1.2, R15.1, VD1.2 (A), VT2.1 (B), VT3.3 (B)
/MCU_RST: DD1.9 (RST), DD14.5 (Q), R2.2
/PROM_RD: DD3.1 (Ea1), DD11.8
/Port67_ISA_Write_p: DD6.11 (LE), DD14.11 (C), DD15.4
/Port67_MCU_Write_p: DD7.11 (LE), DD15.2
/Port89_ISA_Write_p: DD8.11 (LE), DD15.12
/nISA_RESET: DD14.4 (~S), DD15.10
DD5-OE: DD3.7 (Q0a), DD5.20
DD5-WE: DD5.21, X7a1.2 (C)
External_Code_Access: DD1.31 (*EA/VPP), X5.2 (C)
GND: C1.2, C2.1, C12.2, CF1.1, CF2.2, CF3.1, CF4.1, CF5.2, CF6.1, CF7.1, CF8.2, CF9.1, CF10.1, CF11.1, DD1.20 (GND), DD2.1 (OE), DD2.10 (GND), DD3.8 (GND), DD4.12 (GND), DD4.18 (~CS), DD5.12, DD5.18, DD6.10 (GND), DD7.10 (GND), DD8.1 (OE), DD8.10 (GND), DD9.10 (GND), DD10.7 (GND), DD11.7 (GND), DD12.8 (GND), DD13.2 (D), DD13.7 (GND), DD13.12 (D), DD14.7 (GND), DD15.7 (GND), DD16.7 (GND), DD17.7 (GND), DD18.7 (GND), R5.2, R8.1, R10.2, R13.1, R14.1, SAjp1.1, SAjp2.1, SAjp3.1, SAjp4.1, SAjp5.1, SAjp6.1, SAjp7.1, SAjp8.1, VT4.1 (E), X5.3 (B), XA.2.1, XA.2.10, XA.2.31, XL1.0 (PAD), XL1.6, XL1.7, XL1.8, XL1.9, XT0.1 (GND), XT0.10 (GND), XT0.31 (GND)
IRQ: DD10.8, NR1.10 (R9), SAjp9.1, SAjp10.1, SAjp11.1, SAjp12.1, SAjp13.1, SAjp14.1, SAjp15.1, SAjp16.1
ISA_AEN: DD17.4, XA.1.11, XT0.42 (AEN)
ISA_ALE: XT0.28 (ALE)
ISA_BA0: DD14.12 (D), XA.1.31, XT0.62 (BA00)
ISA_BA1: DD12.13 (A0), XA.1.30, XT0.61 (BA01)
ISA_BA2: DD12.3 (A1), XA.1.29, XT0.60 (BA02)
ISA_BA3: DD16.10, XA.1.28, XT0.59 (BA03)
ISA_BA4: DD17.10, XA.1.27, XT0.58 (BA04)
ISA_BA5: DD16.13, XA.1.26, XT0.57 (BA05)
ISA_BA6: DD17.13, XA.1.25, XT0.56 (BA06)
ISA_BA7: DD16.4, XA.1.24, XT0.55 (BA07)
ISA_BA8: DD17.1, XA.1.23, XT0.54 (BA08)
ISA_BA9: DD16.1, XA.1.22, XT0.53 (BA09)
ISA_BA10: XT0.52 (BA10)
ISA_BA11: XT0.51 (BA11)
ISA_BA12: XT0.50 (BA12)
ISA_BA13: XT0.49 (BA13)
ISA_BA14: XT0.48 (BA14)
ISA_BA15: XT0.47 (BA15)
ISA_BA16: XT0.46 (BA16)
ISA_BA17: XT0.45 (BA17)
ISA_BA18: XT0.44 (BA18)
ISA_BA19: XT0.43 (BA19)
ISA_CLK: XT0.20 (CLK)
ISA_D8: XT0.91 (D8)
ISA_D9: XT0.92 (D9)
ISA_D10: XT0.93 (D10)
ISA_D11: XT0.94 (D11)
ISA_D12: XT0.95 (D12)
ISA_D13: XT0.96 (D13)
ISA_D14: XT0.97 (D14)
ISA_D15: XT0.98 (D15)
ISA_DACK0: XT0.70 (~DACK0)
ISA_DACK1: XT0.17 (~DACK1)
ISA_DACK2: XT0.26 (~DACK2)
ISA_DACK3: XT0.15 (~DACK3)
ISA_DACK5: XT0.72 (~DACK5)
ISA_DACK6: XT0.74 (~DACK6)
ISA_DACK7: XT0.76 (~DACK7)
ISA_DB0: DD6.3 (D0), DD7.2 (O0), DD8.3 (D0), DD9.2 (O0), XA.1.9, XT0.40 (DB0)
ISA_DB1: DD6.4 (D1), DD7.5 (O1), DD8.4 (D1), DD9.5 (O1), XA.1.8, XT0.39 (DB1)
ISA_DB2: DD6.7 (D2), DD7.6 (O2), DD8.7 (D2), DD9.6 (O2), XA.1.7, XT0.38 (DB2)
ISA_DB3: DD6.8 (D3), DD7.9 (O3), DD8.8 (D3), DD9.9 (O3), XA.1.6, XT0.37 (DB3)
ISA_DB4: DD6.13 (D4), DD7.12 (O4), DD8.13 (D4), DD9.12 (O4), XA.1.5, XT0.36 (DB4)
ISA_DB5: DD6.14 (D5), DD7.15 (O5), DD8.14 (D5), DD9.15 (O5), XA.1.4, XT0.35 (DB5)
ISA_DB6: DD6.17 (D6), DD7.16 (O6), DD8.17 (D6), DD9.16 (O6), XA.1.3, XT0.34 (DB6)
ISA_DB7: DD6.18 (D7), DD7.19 (O7), DD8.18 (D7), DD9.19 (O7), DD14.2 (D), XA.1.2, XT0.33 (DB7)
ISA_DRQ0: XT0.71 (DRQ0)
ISA_DRQ1: XT0.18 (DRQ1)
ISA_DRQ2: XT0.6 (DRQ2)
ISA_DRQ3: XT0.16 (DRQ3)
ISA_DRQ5: XT0.73 (DRQ5)
ISA_DRQ6: XT0.75 (DRQ6)
ISA_DRQ7: XT0.77 (DRQ7)
ISA_IO: XT0.32 (IO)
ISA_IOCS16: XT0.64 (~IOCS16)
ISA_IOR: DD12.2 (Ea2), XA.2.14, XT0.14 (~IOR)
ISA_IOW: DD12.14 (Eb1), XA.2.13, XT0.13 (~IOW)
ISA_IO_READY: XT0.41 (IO_READY)
ISA_IRQ2: XA.2.4, XT0.4 (IRQ2)
ISA_IRQ3: SAjp9.2, XA.2.25, XT0.25 (IRQ3)
ISA_IRQ4: SAjp10.2, XA.2.24, XT0.24 (IRQ4)
ISA_IRQ5: XT0.23 (IRQ5)
ISA_IRQ6: XT0.22 (IRQ6)
ISA_IRQ7: SAjp11.2, XA.2.21, XT0.21 (IRQ7)
ISA_IRQ10: SAjp12.2, XT0.65 (IRQ10)
ISA_IRQ11: SAjp13.2, XT0.66 (IRQ11)
ISA_IRQ12: SAjp14.2, XT0.67 (IRQ12)
ISA_IRQ14: XT0.69 (IRQ14)
ISA_IRQ15: XT0.68 (IRQ15)
ISA_IRQ_EN_BIT: DD8.16 (O6), DD9.17 (D6), DD10.9
ISA_LA17: XT0.88 (LA17)
ISA_LA18: XT0.87 (LA18)
ISA_LA19: XT0.86 (LA19)
ISA_LA20: XT0.85 (LA20)
ISA_LA21: XT0.84 (LA21)
ISA_LA22: XT0.83 (LA22)
ISA_LA23: XT0.82 (LA23)
ISA_MASTER: XT0.79 (MASTER)
ISA_MEMCS16: XT0.63 (~MEMCS16)
ISA_MEMR: XT0.89 (~MEMR)
ISA_MEMW: XT0.90 (~MEMW)
ISA_OSC: XT0.30 (OSC)
ISA_REFRESH: XT0.19 (~REFRESH)
ISA_RESET: DD15.11, XA.2.2, XT0.2 (RESET)
ISA_SBHE: XT0.81 (SBHE)
ISA_SMEMR: XT0.12 (~SMEMR)
ISA_SMEMW: XT0.11 (~SMEMW)
ISA_TC: XT0.27 (TC)
MCU_A11: DD1.24 (P2-3A11), X4.5, X7.3 (B), X7a1.3 (B)
MCU_A12: DD1.25 (P2-4A12), TP4.1, TP8.1, X4.4
MCU_A13: DD1.26 (P2-5A13), DD3.2 (Ea2), DD3.15 (Eb2), X4.3
MCU_A14: DD1.27 (P2-6A14), DD3.13 (A0), X4.2
MCU_A15: DD1.28 (P2-7A15), DD3.3 (A1), X4.1
MCU_AD0: DD1.39 (P0-0AD0), DD2.3 (D0), DD4.9 (D0), DD5.9, DD6.2 (O0), DD7.3 (D0), NR2.2 (R1), X3.1
MCU_AD1: DD1.38 (P0-1AD1), DD2.4 (D1), DD4.10 (D1), DD5.10, DD6.5 (O1), DD7.4 (D1), NR2.3 (R2), X3.2
MCU_AD2: DD1.37 (P0-2AD2), DD2.7 (D2), DD4.11 (D2), DD5.11, DD6.6 (O2), DD7.7 (D2), NR2.4 (R3), X3.3
MCU_AD3: DD1.36 (P0-3AD3), DD2.8 (D3), DD4.13 (D3), DD5.13, DD6.9 (O3), DD7.8 (D3), NR2.5 (R4), X3.4
MCU_AD4: DD1.35 (P0-4AD4), DD2.13 (D4), DD4.14 (D4), DD5.14, DD6.12 (O4), DD7.13 (D4), NR2.6 (R5), X3.5
MCU_AD5: DD1.34 (P0-5AD5), DD2.14 (D5), DD4.15 (D5), DD5.15, DD6.15 (O5), DD7.14 (D5), NR2.7 (R6), X3.6
MCU_AD6: DD1.33 (P0-6AD6), DD2.17 (D6), DD4.16 (D6), DD5.16, DD6.16 (O6), DD7.17 (D6), NR2.8 (R7), X3.7
MCU_AD7: DD1.32 (P0-7AD7), DD2.18 (D7), DD4.17 (D7), DD5.17, DD6.19 (O7), DD7.18 (D7), NR2.9 (R8), X3.8
MCU_ALE: DD1.30 (ALE/*PROG), DD2.11 (LE)
MCU_Int0: DD1.12 (*INT0P3-2), DD9.13 (D4), DD13.6 (~Q), X1.3
MCU_Int1: DD1.13 (*INT1P3-3), DD9.8 (D3), DD13.9 (Q), X1.4
MCU_P1-0: DD1.1 (P1-0), X2.1
MCU_P1-1: DD1.2 (P1-1), X2.2
MCU_P1-2: DD1.3 (P1-2), X2.3
MCU_P1-3: DD1.4 (P1-3), X2.4
MCU_P1-4: DD1.5 (P1-4), X2.5
MCU_P1-5: DD1.6 (P1-5), X2.6
MCU_P1-6: DD1.7 (P1-6), X2.7
MCU_P1-7: DD1.8 (P1-7), X2.8
MCU_P3-4: DD1.14 (T0P3-4), DD14.9 (Q), X1.5
MCU_P3-5: DD1.15 (T1_P3-5), DD9.14 (D5), DD10.10, X1.6
MCU_PSEN: DD1.29 (*PSEN), DD11.9
MCU_RD: DD1.17 (*RDP3-7), DD11.10, X1.8
MCU_RXD: DD1.10 (RXDP3-0), DD10.3, DD10.6, R4.2, X1.1
MCU_TXD: DD1.11 (TXDP3-1), DD10.12, DD10.13, X1.2
MCU_WR: DD1.16 (*WRP3-6), DD3.14 (Eb1), X1.7
unnamed: C1.1, DD1.18 (XTAL2), Q1.1
unnamed: C2.2, DD1.19 (XTAL1), Q1.2
unnamed: C3.1, R11.1, R12.1, VD3.2 (A), VT4.2 (C), XL1.3
unnamed: C3.2, R12.2, VT5.2 (B)
unnamed: C12.1, R6.1, R7.1, VT1.2 (C), VT2.2 (C)
unnamed: DD10.1, DD10.2, R3.2, VD2.2 (A)
unnamed: DD10.4, DD10.5, R13.2, VT5.1 (C)
unnamed: DD12.1 (Ea1), DD15.8
unnamed: DD12.15 (Eb2), DD15.9, DD18.8
unnamed: DD16.3, DD18.11
unnamed: DD16.6, DD18.5
unnamed: DD16.8, DD18.1
unnamed: DD16.11, DD18.3
unnamed: DD17.3, DD18.6
unnamed: DD17.6, DD18.12
unnamed: DD17.8, DD18.2
unnamed: DD17.11, DD18.4
unnamed: LD1.1 (K), R4.1
unnamed: LD2.1 (K), R2.1
unnamed: R3.1, R8.2, VT1.1 (E), XL1.2
unnamed: R5.1, VT1.3 (B), VT2.3 (E)
unnamed: R9.2, VT3.1 (E)
unnamed: R9.1, R10.1, VT4.3 (B)
unnamed: R14.2, VD4.1 (K), VT5.3 (E)
Port67_ISA_Read: DD7.1 (OE), DD12.7 (Q0a), DD13.11 (C)
Port67_ISA_Write: DD12.9 (Q0b), DD13.4 (~S), DD15.3
Port67_MCU_Read: DD3.4 (Q3a), DD6.1 (OE), DD13.3 (C)
Port67_MCU_Write: DD3.12 (Q3b), DD13.10 (~S), DD15.1
Port89_ISA_Read: DD9.1 (OE), DD12.6 (Q1a)
Port89_ISA_Write: DD12.10 (Q1b), DD14.3 (C), DD15.13
RAM-A0: DD2.2 (O0), DD4.8 (A0), DD5.8
RAM-A1: DD2.5 (O1), DD4.7 (A1), DD5.7
RAM-A2: DD2.6 (O2), DD4.6 (A2), DD5.6
RAM-A3: DD2.9 (O3), DD4.5 (A3), DD5.5
RAM-A4: DD2.12 (O4), DD4.4 (A4), DD5.4
RAM-A5: DD2.15 (O5), DD4.3 (A5), DD5.3
RAM-A6: DD2.16 (O6), DD4.2 (A6), DD5.2
RAM-A7: DD2.19 (O7), DD4.1 (A7), DD5.1
RAM-A8: DD1.21 (P2-0A8), DD4.23 (A8), DD5.23, X4.8
RAM-A9: DD1.22 (P2-1A9), DD4.22 (A9), DD5.22, X4.7
RAM-A10: DD1.23 (P2-2A10), DD4.19 (A10), DD5.19, X4.6
RAM_Read: DD3.6 (Q1a), DD4.20 (~OE)
RAM_WE: DD4.21 (~WE), X7.2 (C)
RAM_Write: DD3.10 (Q1b), TP6.1, X7.1 (A)
SA1-1: DD16.9, NR1.2 (R1), SAjp1.2
SA1-2: DD17.9, NR1.3 (R2), SAjp2.2
SA1-3: DD16.12, NR1.4 (R3), SAjp3.2
SA1-4: DD17.12, NR1.5 (R4), SAjp4.2
SA1-5: DD16.5, NR1.6 (R5), SAjp5.2
SA1-6: DD17.2, NR1.7 (R6), SAjp6.2
SA1-7: DD16.2, NR1.8 (R7), SAjp7.2
SA1-8: DD9.18 (D7), NR1.9 (R8), SAjp8.2

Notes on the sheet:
PORT 8-9
PORT 6-7
ISA BA3 ISA BA4 ISA BA5 ISA BA6 ISA BA7 ISA BA8 ISA BA9 Port89 Bit7
IRQ

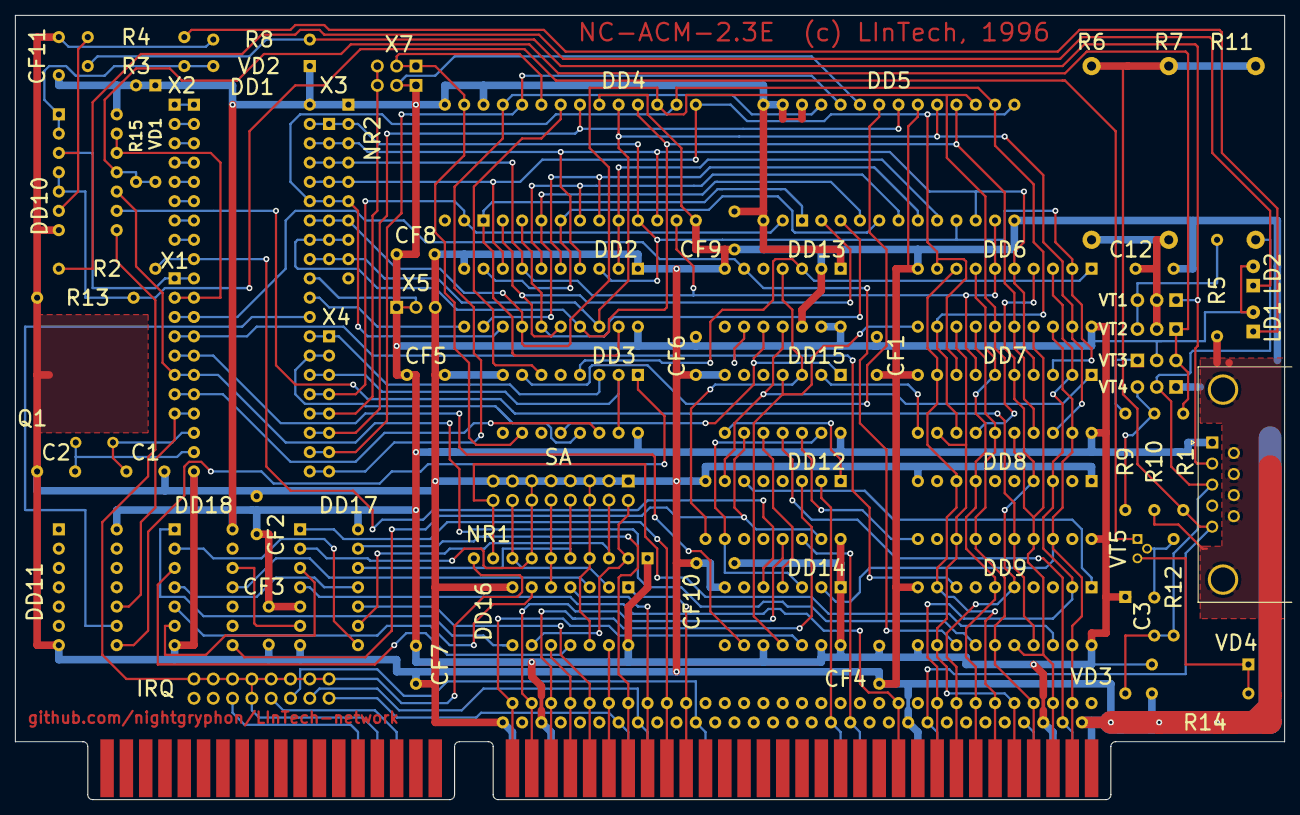
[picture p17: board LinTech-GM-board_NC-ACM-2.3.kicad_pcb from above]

Board: 2 copper layers, 167.0 x 103.2 mm, 97 parts (0 on the bottom side), 127 nets.

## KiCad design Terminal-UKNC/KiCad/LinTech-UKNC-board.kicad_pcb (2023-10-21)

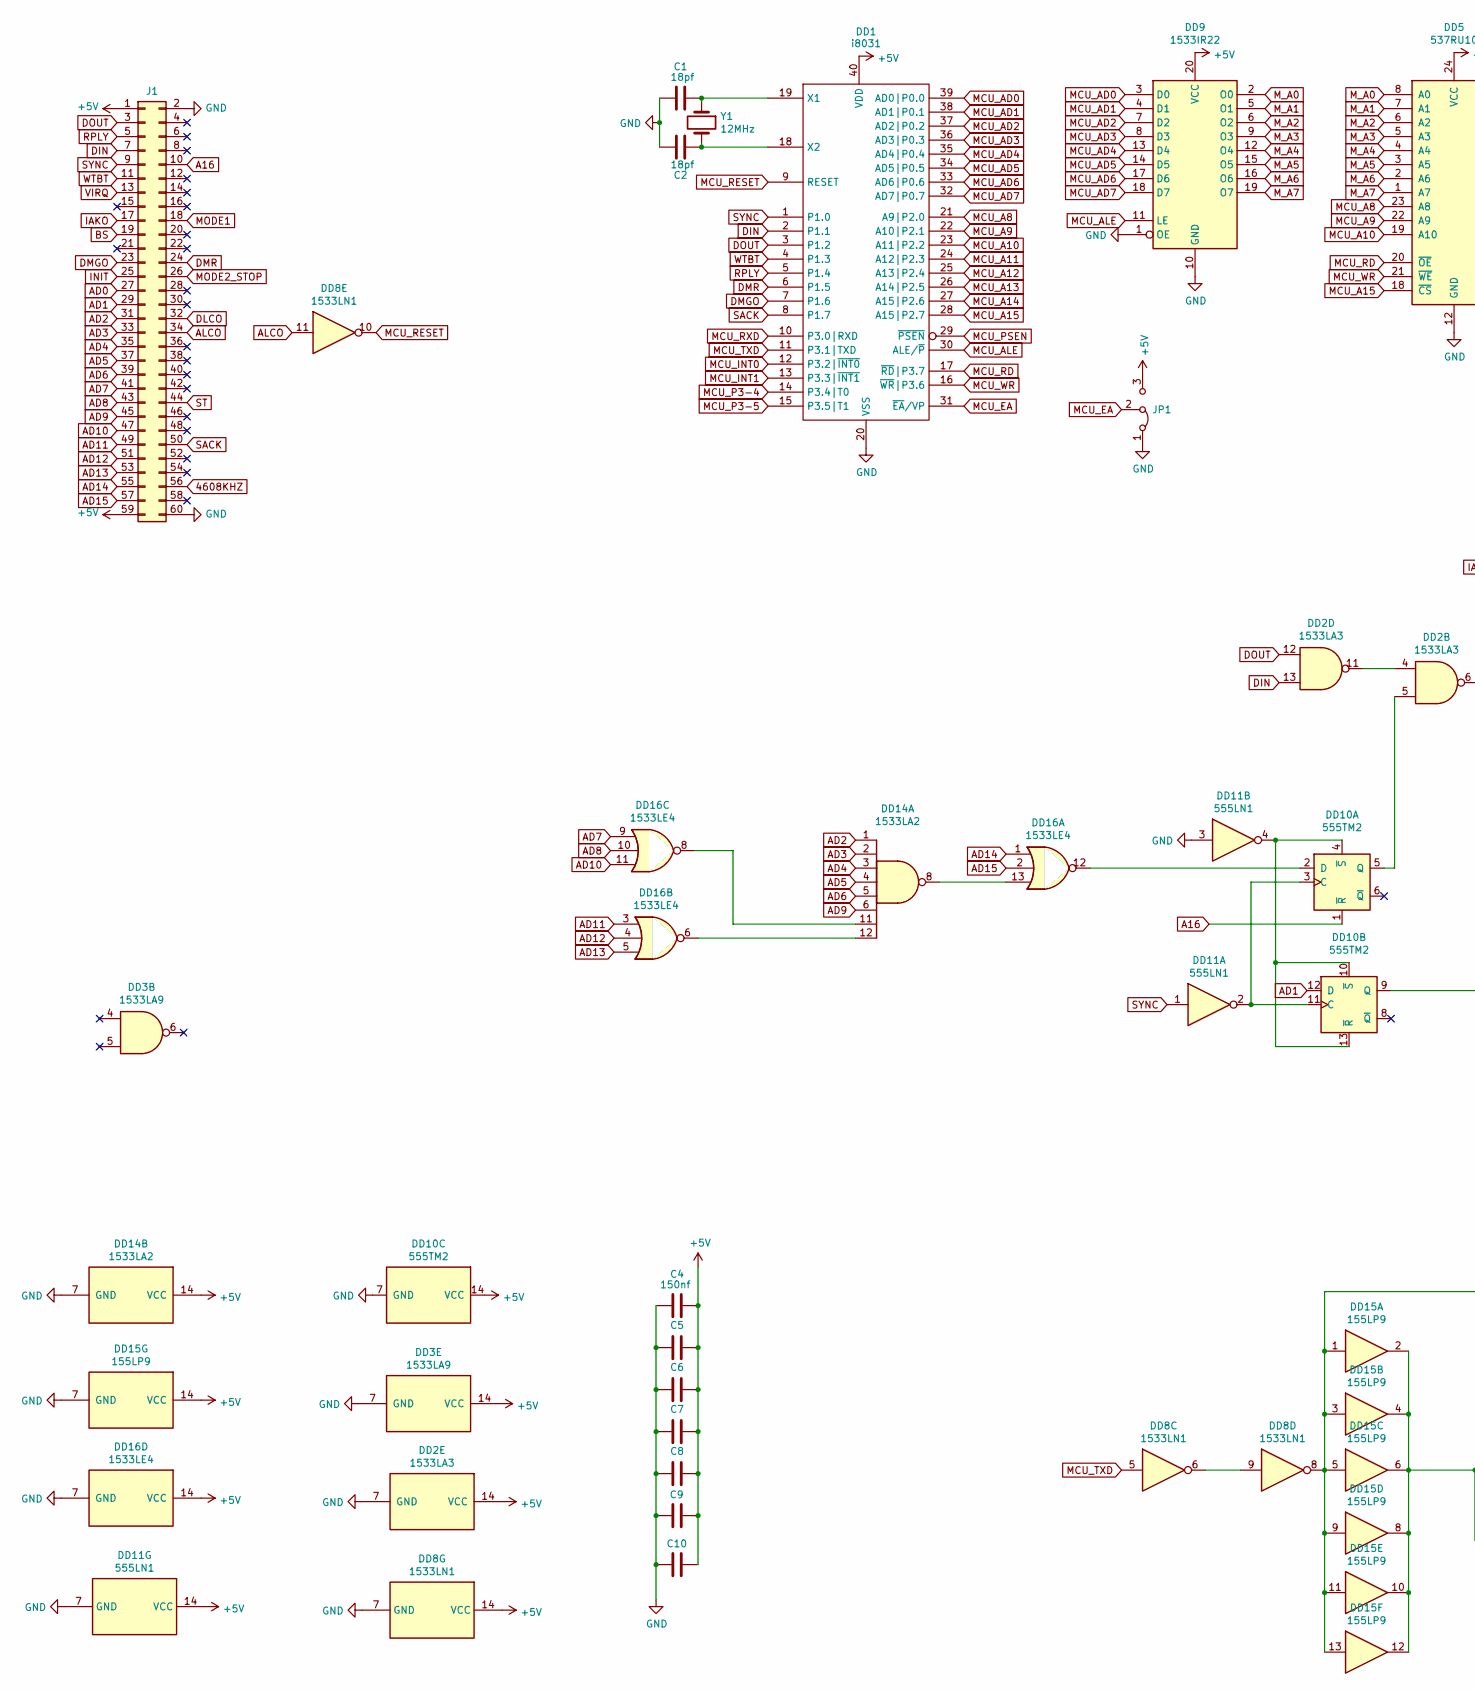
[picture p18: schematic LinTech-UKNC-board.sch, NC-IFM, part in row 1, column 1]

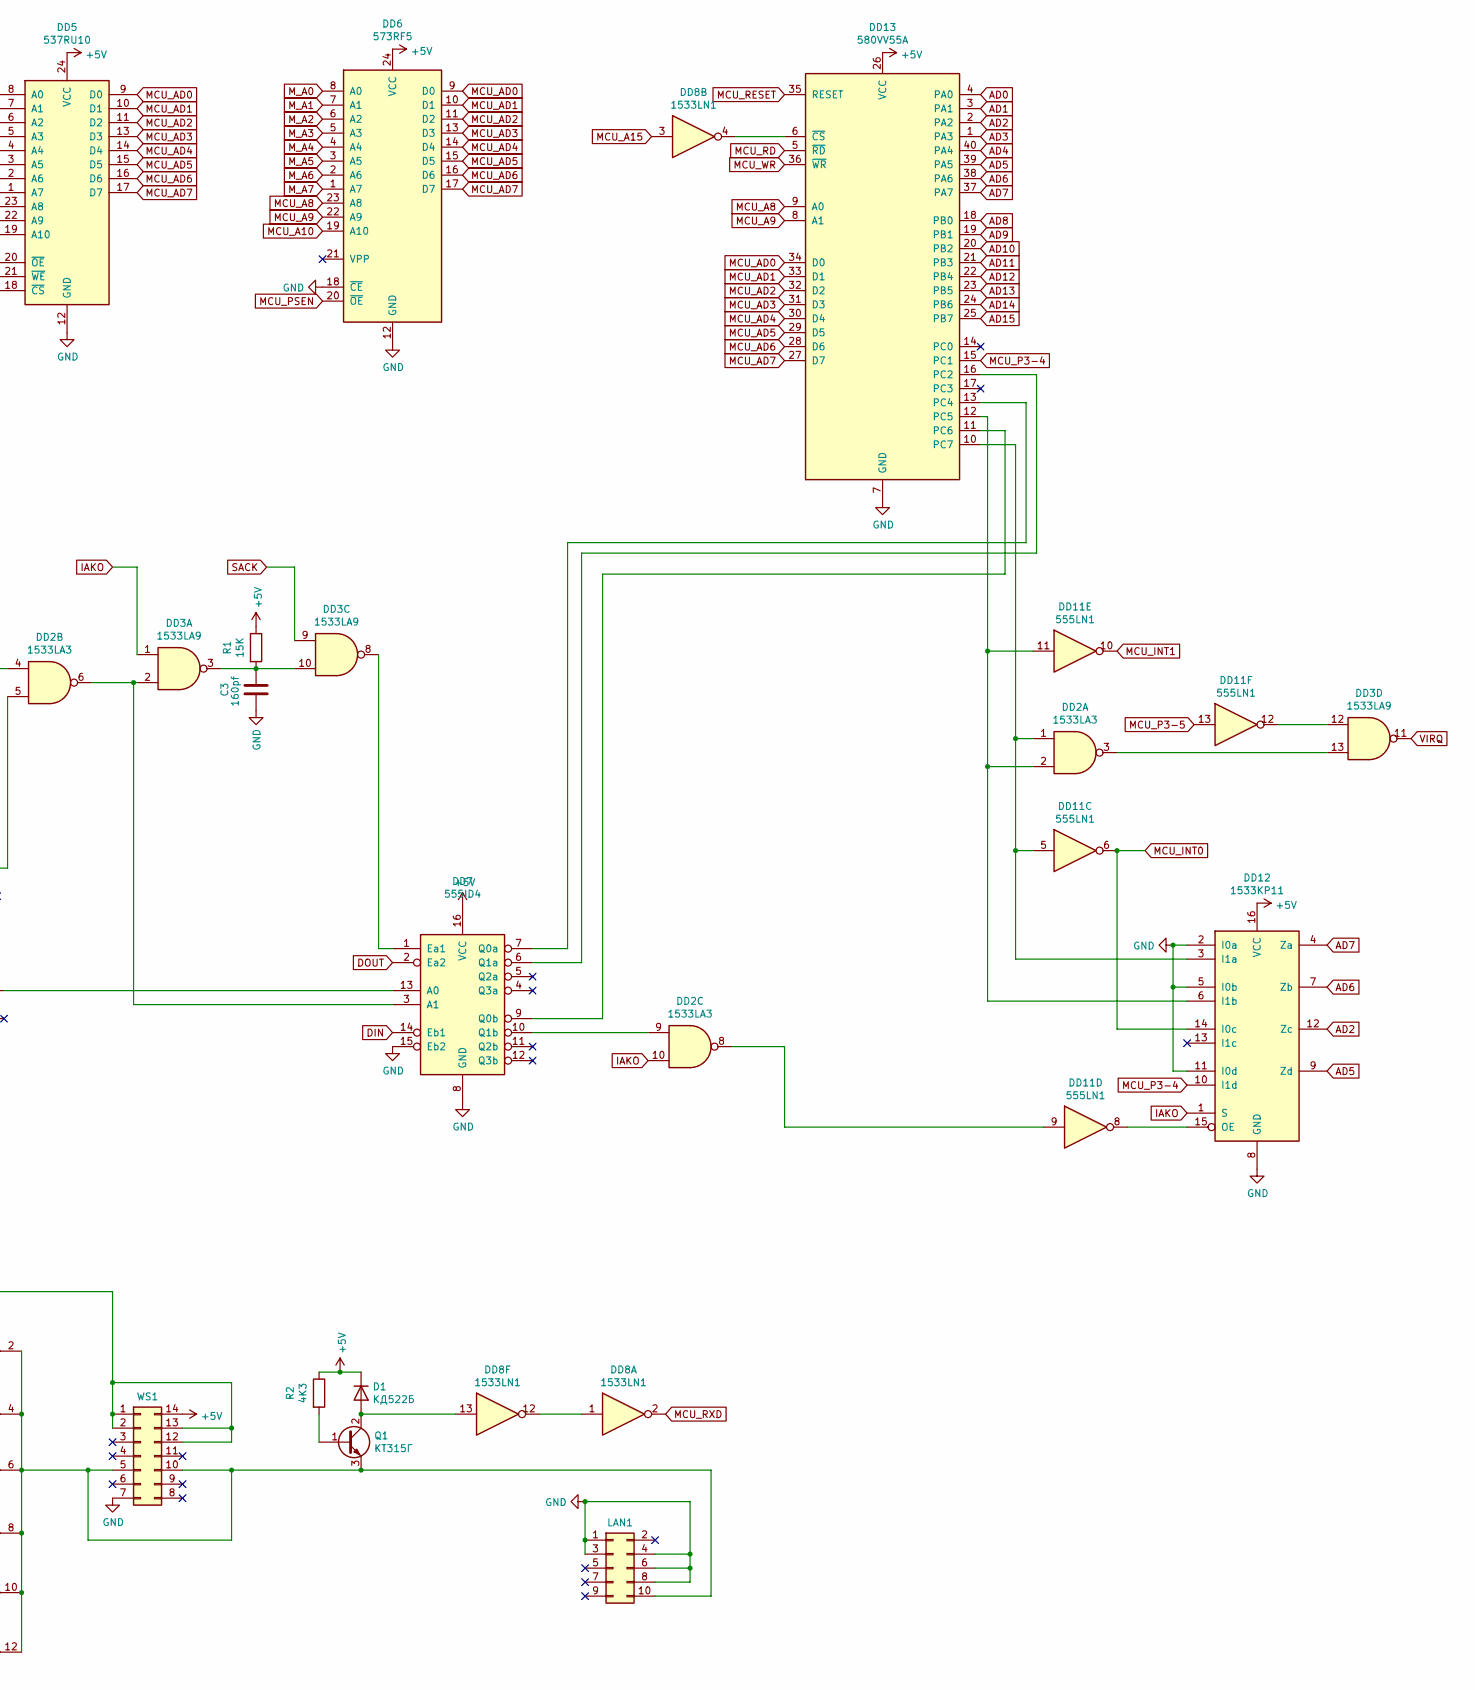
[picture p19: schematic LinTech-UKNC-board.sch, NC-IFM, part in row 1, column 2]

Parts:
C1, C2: 18pf; C_Disc_D5.0mm_W2.5mm_P5.00mm
C3: 160pf; C_Disc_D5.0mm_W2.5mm_P5.00mm
C4, C5, C6, C7, C8, C9, C10: 150nf; C_Disc_D5.0mm_W2.5mm_P5.00mm
D1: КД522Б; D_A-405_P12.70mm_Horizontal
DD1: i8031; DIP-40_W15.24mm
DD2: 1533LA3; DIP-14_W7.62mm
DD3: 1533LA9; DIP-14_W7.62mm
DD5: 537RU10; DIP-24_W15.24mm
DD6: 573RF5; DIP-24_W15.24mm
DD7: 555ID4; DIP-16_W7.62mm
DD8: 1533LN1; DIP-14_W7.62mm
DD9: 1533IR22; DIP-20_W7.62mm
DD10: 555TM2; DIP-14_W7.62mm
DD11: 555LN1; DIP-14_W7.62mm
DD12: 1533KP11; DIP-16_W7.62mm
DD13: 580VV55A; DIP-40_W15.24mm
DD14: 1533LA2; DIP-14_W7.62mm
DD15: 155LP9; DIP-14_W7.62mm
DD16: 1533LE4; DIP-14_W7.62mm
J1: UKNC-CA
JP1: Jumper_3_Bridged12
LAN1: ОНП-КГ-56-10/33х7,4-В53; PinHeader_2x05_P2.54mm_Horizontal
Q1: КТ315Г; PinHeader_1x03_P2.54mm_Vertical
R1: 15K; R_Axial_DIN0309_L9.0mm_D3.2mm_P12.70mm_Horizontal
R2: 4K3; R_Axial_DIN0309_L9.0mm_D3.2mm_P12.70mm_Horizontal
WS1: DIP-14_W7.62mm
Y1: 12MHz; Crystal_HC18-U_Horizontal

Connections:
4608KHZ: J1.56
+5V: C4.2, C5.2, C6.2, C7.2, C8.1, C9.2, C10.2, D1.1 (K), DD1.40 (VDD), DD2.14 (VCC), DD3.14 (VCC), DD5.24 (VCC), DD6.24 (VCC), DD7.16 (VCC), DD8.14 (VCC), DD9.20 (VCC), DD10.14 (VCC), DD11.14 (VCC), DD12.16 (VCC), DD13.26 (VCC), DD14.14 (VCC), DD15.14 (VCC), DD16.14 (VCC), J1.1, J1.59, JP1.3 (B), R1.1, R2.1, WS1.14
A16: DD10.1 (~R), J1.10
AD0: DD13.4 (PA0), J1.27
AD1: DD10.12 (D), DD13.3 (PA1), J1.29
AD2: DD12.12 (Zc), DD13.2 (PA2), DD14.1, J1.31
AD3: DD13.1 (PA3), DD14.2, J1.33
AD4: DD13.40 (PA4), DD14.3, J1.35
AD5: DD12.9 (Zd), DD13.39 (PA5), DD14.4, J1.37
AD6: DD12.7 (Zb), DD13.38 (PA6), DD14.5, J1.39
AD7: DD12.4 (Za), DD13.37 (PA7), DD16.9, J1.41
AD8: DD13.18 (PB0), DD16.10, J1.43
AD9: DD13.19 (PB1), DD14.6, J1.45
AD10: DD13.20 (PB2), DD16.11, J1.47
AD11: DD13.21 (PB3), DD16.3, J1.49
AD12: DD13.22 (PB4), DD16.4, J1.51
AD13: DD13.23 (PB5), DD16.5, J1.53
AD14: DD13.24 (PB6), DD16.1, J1.55
AD15: DD13.25 (PB7), DD16.2, J1.57
ALCO: DD8.11, J1.34
BS: J1.19
DIN: DD1.2 (P1.1), DD2.13, DD7.14 (Eb1), J1.7
DLCO: J1.32
DMGO: DD1.7 (P1.6), J1.23
DMR: DD1.6 (P1.5), J1.24
DOUT: DD1.3 (P1.2), DD2.12, DD7.2 (Ea2), J1.3
GND: C1.2, C2.2, C3.1, C4.1, C5.1, C6.1, C7.1, C8.2, C9.1, C10.1, DD1.20 (VSS), DD2.7 (GND), DD3.7 (GND), DD5.12 (GND), DD6.12 (GND), DD6.18 (~CE), DD7.8 (GND), DD7.15 (Eb2), DD8.7 (GND), DD9.1 (OE), DD9.10 (GND), DD10.7 (GND), DD11.3, DD11.7 (GND), DD12.2 (I0a), DD12.5 (I0b), DD12.8 (GND), DD12.11 (I0d), DD13.7 (GND), DD14.7 (GND), DD15.7 (GND), DD16.7 (GND), J1.2, J1.60, JP1.1 (A), LAN1.1, LAN1.3, LAN1.4, LAN1.6, LAN1.8, WS1.7
IAKO: DD2.10, DD3.1, DD12.1 (S), J1.17
INIT: J1.25
MCU_A8: DD1.21 (A9|P2.0), DD5.23 (A8), DD6.23 (A8), DD13.9 (A0)
MCU_A9: DD1.22 (A10|P2.1), DD5.22 (A9), DD6.22 (A9), DD13.8 (A1)
MCU_A10: DD1.23 (A11|P2.2), DD5.19 (A10), DD6.19 (A10)
MCU_A11: DD1.24 (A12|P2.3)
MCU_A12: DD1.25 (A13|P2.4)
MCU_A13: DD1.26 (A14|P2.5)
MCU_A14: DD1.27 (A15|P2.6)
MCU_A15: DD1.28 (A15|P2.7), DD5.18 (~CS), DD8.3
MCU_AD0: DD1.39 (AD0|P0.0), DD5.9 (D0), DD6.9 (D0), DD9.3 (D0), DD13.34 (D0)
MCU_AD1: DD1.38 (AD1|P0.1), DD5.10 (D1), DD6.10 (D1), DD9.4 (D1), DD13.33 (D1)
MCU_AD2: DD1.37 (AD2|P0.2), DD5.11 (D2), DD6.11 (D2), DD9.7 (D2), DD13.32 (D2)
MCU_AD3: DD1.36 (AD3|P0.3), DD5.13 (D3), DD6.13 (D3), DD9.8 (D3), DD13.31 (D3)
MCU_AD4: DD1.35 (AD4|P0.4), DD5.14 (D4), DD6.14 (D4), DD9.13 (D4), DD13.30 (D4)
MCU_AD5: DD1.34 (AD5|P0.5), DD5.15 (D5), DD6.15 (D5), DD9.14 (D5), DD13.29 (D5)
MCU_AD6: DD1.33 (AD6|P0.6), DD5.16 (D6), DD6.16 (D6), DD9.17 (D6), DD13.28 (D6)
MCU_AD7: DD1.32 (AD7|P0.7), DD5.17 (D7), DD6.17 (D7), DD9.18 (D7), DD13.27 (D7)
MCU_ALE: DD1.30 (ALE/~P), DD9.11 (LE)
MCU_EA: DD1.31 (~EA~/VP), JP1.2 (C)
MCU_INT0: DD1.12 (P3.2|~INT0), DD11.6, DD12.14 (I0c)
MCU_INT1: DD1.13 (P3.3|~INT1), DD11.10
MCU_P3-4: DD1.14 (P3.4|T0), DD12.10 (I1d), DD13.15 (PC1)
MCU_P3-5: DD1.15 (P3.5|T1), DD11.13
MCU_PSEN: DD1.29 (~PSEN), DD6.20 (~OE)
MCU_RD: DD1.17 (~RD~|P3.7), DD5.20 (~OE), DD13.5 (~RD~)
MCU_RESET: DD1.9 (RESET), DD8.10, DD13.35 (RESET)
MCU_RXD: DD1.10 (P3.0|RXD), DD8.2
MCU_TXD: DD1.11 (P3.1|TXD), DD8.5
MCU_WR: DD1.16 (~WR~|P3.6), DD5.21 (~WE), DD13.36 (~WR~)
MODE1: J1.18
MODE2_STOP: J1.26
M_A0: DD5.8 (A0), DD6.8 (A0), DD9.2 (O0)
M_A1: DD5.7 (A1), DD6.7 (A1), DD9.5 (O1)
M_A2: DD5.6 (A2), DD6.6 (A2), DD9.6 (O2)
M_A3: DD5.5 (A3), DD6.5 (A3), DD9.9 (O3)
M_A4: DD5.4 (A4), DD6.4 (A4), DD9.12 (O4)
M_A5: DD5.3 (A5), DD6.3 (A5), DD9.15 (O5)
M_A6: DD5.2 (A6), DD6.2 (A6), DD9.16 (O6)
M_A7: DD5.1 (A7), DD6.1 (A7), DD9.19 (O7)
unnamed: C1.1, DD1.19 (X1), Y1.1
unnamed: C2.1, DD1.18 (X2), Y1.2
unnamed: C3.2, DD3.3, DD3.10, R1.2
unnamed: D1.2 (A), DD8.13, Q1.2 (C)
unnamed: DD2.3, DD3.13
unnamed: DD2.6, DD3.2, DD7.3 (A1)
unnamed: DD2.9, DD7.10 (Q1b)
unnamed: DD2.4, DD2.11
unnamed: DD3.8, DD7.1 (Ea1)
unnamed: DD8.1, DD8.12
unnamed: DD8.6, DD8.9
unnamed: DD10.2 (D), DD16.12
unnamed: DD2.5, DD10.5 (Q)
unnamed: DD7.13 (A0), DD10.9 (Q)
unnamed: DD10.4 (~S), DD10.10 (~S), DD10.13 (~R), DD11.4
unnamed: DD10.3 (C), DD10.11 (C), DD11.2
unnamed: DD2.1, DD11.5, DD12.3 (I1a), DD13.10 (PC7)
unnamed: DD11.8, DD12.15 (OE)
unnamed: DD2.8, DD11.9
unnamed: DD2.2, DD11.11, DD12.6 (I1b), DD13.12 (PC5)
unnamed: DD3.12, DD11.12
unnamed: DD8.4, DD13.6 (~CS~)
unnamed: DD7.9 (Q0b), DD13.11 (PC6)
unnamed: DD7.7 (Q0a), DD13.13 (PC4)
unnamed: DD7.6 (Q1a), DD13.16 (PC2)
unnamed: DD14.8, DD16.13
unnamed: DD14.11, DD16.8
unnamed: DD14.12, DD16.6
unnamed: DD8.8, DD15.1, DD15.3, DD15.5, DD15.9, DD15.11, DD15.13, WS1.1, WS1.2, WS1.12, WS1.13
unnamed: DD15.2, DD15.4, DD15.6, DD15.8, DD15.10, DD15.12, LAN1.10, Q1.3 (E), WS1.5, WS1.10
unnamed: Q1.1 (B), R2.2
RPLY: DD1.5 (P1.4), J1.5
SACK: DD1.8 (P1.7), DD3.9, J1.50
ST: J1.44
SYNC: DD1.1 (P1.0), DD11.1, J1.9
VIRQ: DD3.11, J1.13
WTBT: DD1.4 (P1.3), J1.11

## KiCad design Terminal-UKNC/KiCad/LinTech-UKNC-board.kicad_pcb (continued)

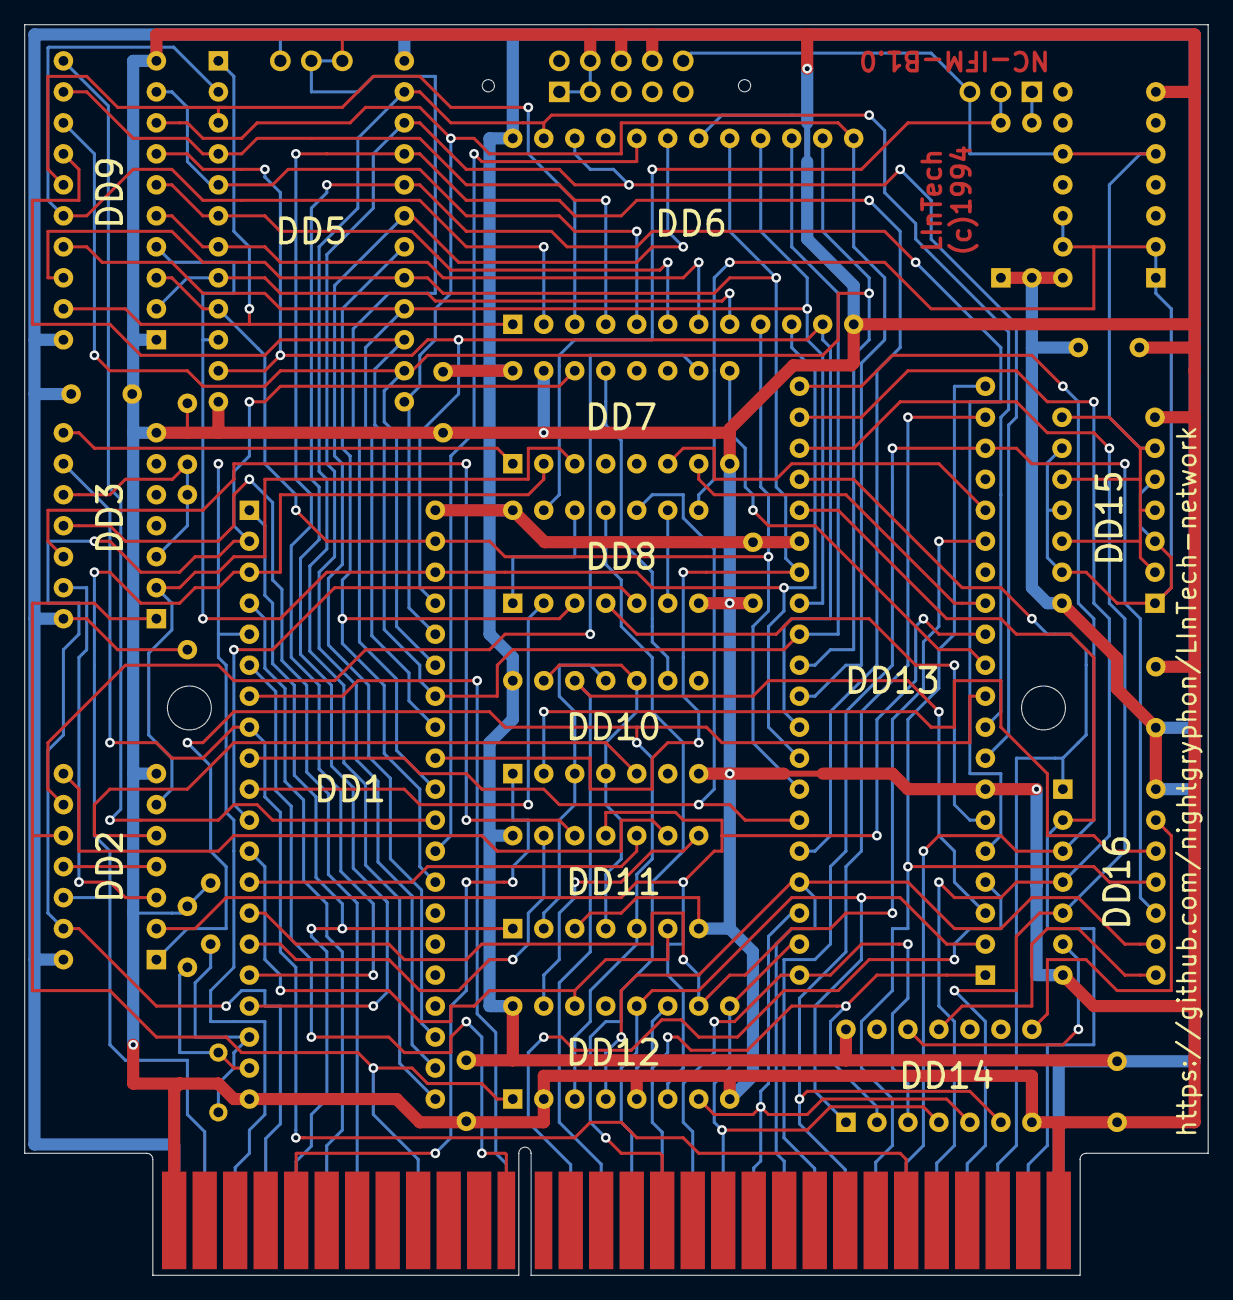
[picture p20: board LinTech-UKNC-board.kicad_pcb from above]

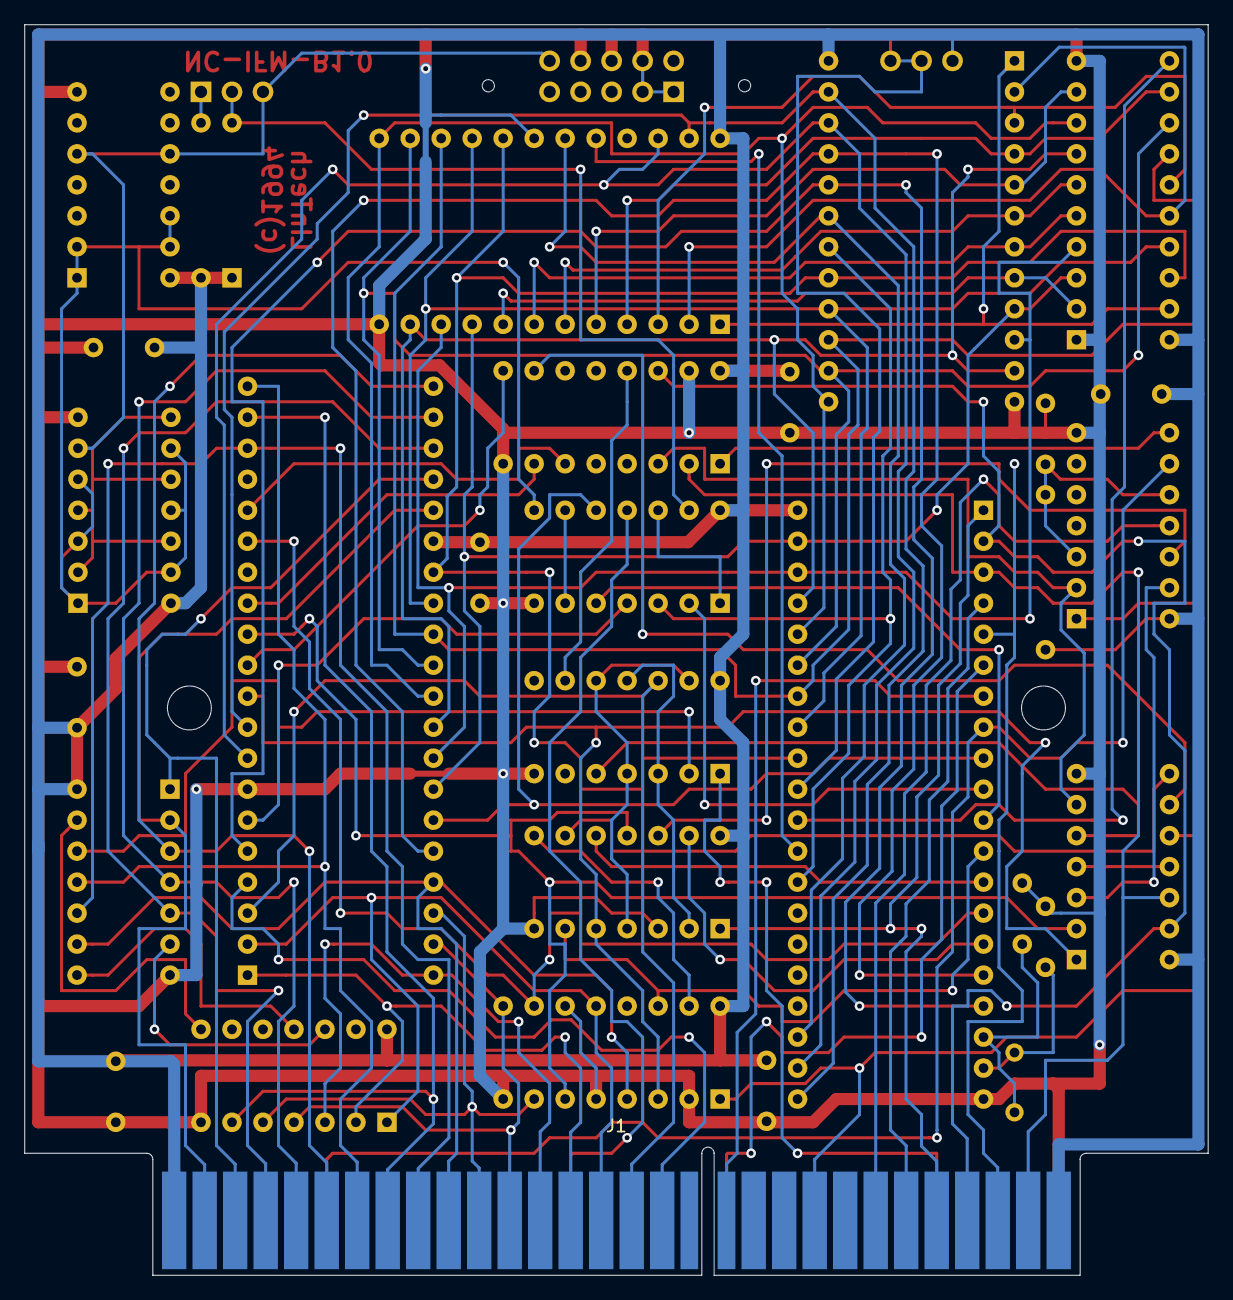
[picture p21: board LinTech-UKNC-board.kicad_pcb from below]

Board: 2 copper layers, 97.0 x 102.5 mm, 34 parts (2 on the bottom side), 93 nets.

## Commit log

2023-10-17 Initial 2
    [LinTech-GM-board_NC-ACM-2.2.kicad_pcb, LinTech-GM-board_NC-ACM-2.2.sch, LinTech-UKNC-board.kicad_pcb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]
2023-10-19 Update GM schematic, README, split LInTech software archive
    [LinTech-GM-board_NC-ACM-2.2.kicad_pcb, LinTech-GM-board_NC-ACM-2.2.sch]
2023-10-19 Update GM board silkscreen and 3D render
    [LinTech-GM-board_NC-ACM-2.2.kicad_pcb]
2023-10-21 Fix footprint drill diameters
    [LinTech-GM-board_NC-ACM-2.2.kicad_pcb, LinTech-GM-board_NC-ACM-2.2.sch, LinTech-UKNC-board.kicad_pcb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]
2023-10-21 Adjust test pads, track width, DB9
    [LinTech-GM-board_NC-ACM-2.2.kicad_pcb, LinTech-GM-board_NC-ACM-2.2.sch]
2023-10-21 Rename root folders
    [LinTech-GM-board_NC-ACM-2.2.kicad_pcb, LinTech-GM-board_NC-ACM-2.2.sch, LinTech-UKNC-board.kicad_pcb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]
2023-10-25 FIX DD9 pin 13 wire, add R15 placeholder
    [LinTech-GM-board_NC-ACM-2.2.kicad_pcb, LinTech-GM-board_NC-ACM-2.2.sch]
2023-10-28 Server board NC-ACM-2.3E
    [LinTech-GM-board_NC-ACM-2.3.kicad_pcb, LinTech-GM-board_NC-ACM-2.3.sch]

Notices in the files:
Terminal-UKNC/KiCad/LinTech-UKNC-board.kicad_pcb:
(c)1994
